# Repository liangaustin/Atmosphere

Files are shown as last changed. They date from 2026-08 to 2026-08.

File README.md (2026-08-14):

# Atmosphere：野外溪流 / 漂流点山洪与泥石流智能监测预警








`Atmosphere` 是一套面向**民间自发漂流活动与野外游泳区域（野泳池）**的低成本、高实效智能监测预警系统。它通过部署在溪流/漂流点的传感器单元，实时采集**土壤湿度、水流速、风速、温湿度**等环境数据，用多因子数学模型判定山洪与泥石流风险等级（0~3 级），并通过**网页监控 + 现场 LCD** 双端呈现，在危险来临前为现场人员争取撤离时间。

> ⚠️ 本系统是**辅助决策工具**，不替代救生员与现场安全管理。山洪预警的黄金法则是**上游预警**——请结合上游雨量/水位遥测站构成完整预警链。
> ⚠️ This is a **decision-support tool**, not a substitute for lifeguards or on-site safety management. The golden rule of flash-flood warning is **upstream early warning** — integrate with upstream rainfall/water-level stations for a complete chain.

## 目录 / Contents

- [主要功能 / Features](#主要功能--features)
- [项目背景 / Background](#项目背景--background)
- [团队分工 / Team](#团队分工--team)
- [硬件方案 / Hardware](#硬件方案--hardware)
- [预警模型 / Warning Model](#预警模型--warning-model)
- [快速开始 / Quick Start](#快速开始--quick-start)
- [项目结构 / Structure](#项目结构--structure)
- [版本历史 / Version History](#版本历史--version-history)
- [文档索引 / Docs](#文档索引--docs)
- [已知限制 / Known Limitations](#已知限制--known-limitations)
- [常见问题 / FAQ](#常见问题--faq)
- [二次开发 / Development](#二次开发--development)
- [贡献 / Contributing](#贡献--contributing)

---

## 主要功能 / Features

- **多传感器融合监测**：土壤湿度、水流速、风速、温湿度四路数据，同一块 Arduino Nano 采集。
- **山洪预警**：山洪路径 F（流量水平 + 流量突变），不受土壤门槛限制，流量暴涨即触发。
- **泥石流预警**：多因子危险指数 D（土湿 + 流量 + 突变 + 涨幅），含土壤饱和度门槛与滑动基准自适应。
- **分级预警**：0=正常 / 1=一级 / 2=二级 / 3=三级（**数字越大越严重**），网页 + LCD 双端显示。
- **现场 LCD**：1602 I2C 屏实时显示风速 / 土湿 / 流速 / 预警等级，不依赖电脑即可观测。
- **综合监控网页**：单页显示四卡 + 实时曲线 + 预警详情（端口 8080），支持水泵 PWM 滑块远程调速。
- **滑动基准自适应**：24 小时窗口 [P10,P95] 分位数归一化，自动适应当地气候，冷启动 15 分钟。
- **滞回防抖**：预警触发后保持（一级 10s / 二级 15s / 三级 20s），避免等级闪烁。
- **断线自愈**：传感器断线检测 + 串口自动重连 + 水泵独立供电防复位。

---

## 项目背景 / Background

民间自发漂流、野泳等亲水活动在山区溪流（天然河道）十分常见，但普遍缺乏有效监管，险情响应滞后。夏季短历时强降雨引发的山洪，可在数分钟内将涓涓细流变成汹涌洪流——据水利部副部长叶建春在国新办发布会介绍（2020年6月），**多年统计下山洪灾害伤亡人数约占洪涝灾害伤亡人数的 70%**，其中涉水游泳、溯溪属于高风险行为。

**核心目标**：以单点 300-400 元的低成本硬件，为漂流点 / 野泳区提供「采集 → 判断 → 预警 → 撤离」的完整闭环，同时保护周边平民安全。

---

## 团队分工 / Team

| 模块 / Module | 职责 / Responsibility | 负责人 / Lead |
|---|---|---|
| 硬件 / Hardware | 检测（收集数据） | 王立辉（Wang Li Hui） |
| 软件 / Software | Web APP（监控、警报、水泵控制） | 梁振宇（Austin Liang） |
| 预测 / Prediction | AI（分析数据、判断风险） | 待定 / TBD |

---

## 硬件方案 / Hardware

### 传感器单元（单点成本 300-400 元）

| 部件 / Part | 型号 / Spec | 接线 / Wiring |
|---|---|---|
| 主控 / MCU | Arduino Nano（ATmega328P，Optiboot，115200） | FQBN `arduino:avr:nano:cpu=atmega328` |
| 土壤湿度 / Soil | 电容式，AO→A2，DO→D2 | VCC→5V，GND→GND，断线检测（raw=1023 或抖动>200） |
| 水流速 / Flow | YF-S401 霍尔流量计 | 红→5V，黄→D8（信号），黑→GND；系数 3433.8 |
| 风速 / Wind | 三杯式风速计（0~5V 模拟输出） | 红→A0，黑→GND；V=ADC×5/1024，km/h=100×V |
| 温湿度 / DHT11 | 数字单总线 | s→D4，v→5V，g→GND |
| 水泵 / Pump | 直流抽水泵，D9 PWM 调速 | 软启动步长 10/20ms；**独立供电 + 共地** |
| 现场显示 / LCD | 1602 I2C（地址 0x27） | SCL→A5，SDA→A4 |
| 联网 / Network | NB-IoT 主 + LoRa 备（规划） | 低功耗、小数据量 |

> ⚠️ **供电铁律**：水泵必须**独立供电**（单独 5V 电源，只共地）。从 Arduino 5V 取电会拉垮 5V → CH340 掉电 → 板子复位断联。

### 软件环境

- Python 3（pyserial）+ Arduino IDE / arduino-cli
- 浏览器访问综合监控网页（http://localhost:8080）

---

## 预警模型 / Warning Model

**等级体系（数字越大越严重）**：`0 = 正常 / 1 = 一级 / 2 = 二级 / 3 = 三级（最高）`

```
最终等级 = max(泥石流 D, 山洪 F, 风速, 流量尖峰, 突变, 土壤饱和)   ← 0~3
```

| 路径 / Path | 公式 / Formula | 说明 / Note |
|---|---|---|
| 泥石流 D | `D = 0.30·S̄ + 0.35·Q̄ + 0.20·dQ̄ + 0.15·ΔS̄` | 土壤 <60% 时跳过本路径 |
| 山洪 F | `F = 0.60·Q̄ + 0.40·dQ̄` | 独立于土壤门槛，流量暴涨即触发 |
| 风速 | ≥25 / ≥40 / ≥60 km/h | 分别触发一级 / 二级 / 三级 |
| 流量尖峰 | 秒级变化率超当地 P95 | 二级；归一化 ≥0.8 → 一级 |
| 突变 | 土壤 5s 涨 ≥20% / 风速 60s 涨 ≥12 km/h | 立即一级 |
| 土壤饱和 | ≥85% 或超当地 P90 | 至少一级（不依赖流量） |

- **阈值**：D/F ≥ 0.45 → 一级；≥ 0.55 → 二级；≥ 0.75 → 三级。
- **滑动基准**：24h 窗口 [P10,P95] 归一化，冷启动 15 分钟；数据不足回退绝对值（Q_MAX=3 L/min、DQ_MAX=0.5，对齐 YF-S401 实测）。
- **滞回保持**：升级立即生效并保持；降级需超过保持时间（一级 10s / 二级 15s / 三级 20s）。
- 完整推导见 [`demo1/algorithm-iterations/`](demo1/algorithm-iterations/README.md)（v1/v2 技术文档，中英双语）。

---

## 快速开始 / Quick Start

```bash
# 1. 烧录固件（Arduino IDE，板卡 Nano + 新 Bootloader，115200）
#    demo1/zh-CN/第二版算法部分/beta5/FlowSensor.ino
#    或 arduino-cli：
#    arduino-cli compile --fqbn arduino:avr:nano:cpu=atmega328 <ino路径>
#    arduino-cli upload -p /dev/cu.usbserial-xxxx --fqbn arduino:avr:nano:cpu=atmega328 <ino路径>

# 2. 启动服务端（串口 /dev/cu.usbserial-14120）
cd demo1/zh-CN/第二版算法部分/beta5/
python3 -u server.py

# 3. 打开网页
http://localhost:8080
```

---

## 项目结构 / Structure

```
Atmosphere/
├── README.md                  # 本文件（新版导航）/ this file
├── README_CLASSIC.md          # 旧版 README 存档 / classic README archive
├── demo1/                     # Demo 1：算法归档 + 文档（zh-CN / en-US / weather / media）
│   ├── README.md              # demo1 详细导航（徽章 + 结构 + 快速开始）
│   ├── zh-CN/                 # 中文版：第一版算法部分(beta1-4) + 第二版算法部分(beta5)
│   ├── en-US/                 # 英文版（同结构）
│   ├── algorithm-iterations/  # 数学预警模型技术文档（v1/v2，中英）
│   ├── weather/               # 风速 + 温湿度模块（王立辉）
│   └── media/                 # 演示图片与视频
├── AustinLiang/               # 梁振宇工作区（土壤湿度）
├── wanglihui/                 # 王立辉工作区（风速）
└── GJJ/                       # 团队成员工作区
```

> 📂 **结构约定**：demo1 内中间层 = **算法版本**（第一版算法部分 = beta1-4，第二版算法部分 = beta5 起），最内层 = **实现迭代**（beta）。

---

## 版本历史 / Version History

| 版本 / Version | 算法 / Algorithm | 核心改动 / Key changes |
| --- | --- | --- |
| beta1 | v1 | 原始算法 D<0.30 无门槛；水泵 D7 数字开关 |
| beta2 | v1 | 加门槛（土壤<60%）+ 三级阈值 0.30→0.45 |
| beta3 | v1 | 水泵 D9 PWM 调速 + 网页滑块 + 功率显示 |
| beta4 | v1 | 尖峰滑动基准（自适应 P95）+ 整机功率（**Demo 1 最终版**） |
| **beta5** | **v2** | **LCD 显示（风速/土湿/流速/预警 0-3）+ 算法 v2（标定对齐、山洪 F、滞回、土壤饱和）+ 温湿度本地** |

> 🏁 **规划 / Plan**：Demo 1 完结于 beta4；beta5 起进入算法迭代阶段（数学预警模型 v2）。超声波水位方案已砍（与流速重叠，不做曼宁 70%）。

---

## 文档索引 / Docs

| 位置 / Path | 说明 / Description |
| --- | --- |
| [`demo1/README.md`](demo1/README.md) | Demo 1 详细导航（目录结构、快速开始、版本历史） |
| [`demo1/algorithm-iterations/`](demo1/algorithm-iterations/README.md) | 数学预警模型技术文档（v1/v2，中英双语，含优势/缺陷/迭代记录） |
| [`demo1/weather/`](demo1/weather/README.md) | 风速 + 温湿度模块（王立辉，网络服务 + Arduino 代码） |
| `demo1/media/` | 演示图片与视频 |

---

## 已知限制 / Known Limitations

1. **流量计量程窄 / Flow sensor range**：YF-S401 实测 0.05~3 L/min，真实洪水流量超量程——v2 标定参数面向当前测试环境，换环境需重新标定。
2. **突变阈值为经验值 / Empirical surge thresholds**：土壤 5s+20%、风速 60s+12km/h 未做统计标定。
3. **LCD 仅 ASCII / ASCII-only LCD**：1602 无中文字库，现场人员需熟悉 0~3 数字含义。
4. **硬阈值分级 / Hard thresholds**：0.45/0.55/0.75 阶梯跳变，无置信度/持续性判定（滞回已缓解闪断）。

---

## 常见问题 / FAQ

**Q1：水泵一开 Arduino 就重启/断连？**
水泵不能从 Arduino 5V 取电（会拉垮 5V → CH340 掉电 → 板子复位）。必须**独立 5V 电源**，GND 与 Arduino 共地，D9 只发 PWM 信号。

**Q2：LCD 不亮 / 花屏？**
① 检查 I2C 地址（默认 0x27，部分模块是 0x3F，改固件 `lcd(0x27, 16, 2)`）；② 确认 SCL→A5、SDA→A4 没接反；③ 旋转背光电位器调对比度。

**Q3：流速一直为 0？**
YF-S401 最小启动流量 0.3 L/min，低于此值转子不转（吹气测不了，必须通水）。接线：红→5V，黄→D8（信号），黑→GND。

**Q4：风速数值异常 / 静止也有读数？**
三杯式风速计部分型号存在零点偏移（静止时输出 ~0.1-0.2V ≈ 10-20 km/h）。可在固件里读静止 ADC 值做零点校准（读数减去零点再换算）。

**Q5：网页风速显示 0 / 离线？**
风速默认来自外部电脑 HTTP 服务（`192.168.1.200:8001/wind`），该服务离线时风速路径失效。风速传感器接入本机 A0 后自动切换本地模式（`wind_source: local`）。

**Q6：串口连不上 / 找不到端口？**
拔插 USB 后端口号会变，用 `ls /dev/cu.* | grep usbserial` 确认，改 `server.py` 里的 `SERIAL_PORT`。烧录时波特率选 115200（Optiboot 新 Bootloader）。

**Q7：预警一直不触发？**
① 土壤 <60% 时泥石流路径跳过（正常）；② 滑动基准冷启动需 15 分钟；③ 检查网页预警卡里的 D/F 数值是否在阈值附近（0.45/0.55/0.75）。

---

## 二次开发 / Development

- **算法迭代**：新算法版本在 `demo1/algorithm-iterations/` 归档，每代一份技术文档（优势 / 缺陷 / 特点），随迭代更新。
- **固件**：`FlowSensor.ino` 模块化，新增传感器 = 加引脚定义 + 每秒块加采集 + JSON 加字段。
- **服务端**：`server.py` 内嵌网页 + 预警模型，五路径独立计算，可单独迭代。
- **协作开发**：双 OpenClaw 协作（桥 8090 + 对端 8131），任务经桥下发，代码经桥/仓库同步。

---

## 贡献 / Contributing

欢迎提交 Issue 与 PR。涉及硬件接线、标定参数、算法阈值的改动，请在提交前更新对应文档（`demo1/algorithm-iterations/`）。本项目为教学 / 竞赛 / 公益性质，文档一律不署名。

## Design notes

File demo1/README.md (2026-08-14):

# 🌊 Atmosphere — Demo 1

> **山洪 + 泥石流智能监测预警 · 野外溪流 / 漂流点**
> **Flash-flood & debris-flow early warning for outdoor streams & drifting sites**







---

## 📑 目录 / Contents

- [📖 项目简介 / Overview](#-项目简介--overview)
- [🎯 应用场景 / Scenarios](#-应用场景--scenarios)
- [🏗️ 系统架构 / Architecture](#%EF%B8%8F-系统架构--architecture)
- [🔌 硬件连接 / Hardware Wiring](#-硬件连接--hardware-wiring)
- [📁 目录结构 / Folder Structure](#-目录结构--folder-structure)
- [🚀 快速开始 / Quick Start](#-快速开始--quick-start)
- [🧠 预警模型 / Warning Model](#-预警模型--warning-model)
- [📜 版本历史 / Version History](#-版本历史--version-history)
- [📄 文档索引 / Docs](#-文档索引--docs)
- [⚠️ 已知问题 / Known Issues](#️-已知问题--known-issues)

---

## 📖 项目简介 / Overview

**中文**：Atmosphere 面向野外溪流、漂流点等场景，实时采集**土壤湿度、水流速、风速、温湿度**四类环境数据，通过网页与 LCD 双端监控，用数学模型（泥石流危险指数 + 山洪流量近似 + 滑动基准 + 滞回保持）输出 **0~3 分级预警**，辅助判断山洪、泥石流风险。Demo 1 打通「采集 → 控制 → 监控 → 预警」全链路。

**English**: Atmosphere monitors soil moisture, water flow, wind speed, and temperature/humidity at outdoor streams and drifting sites. It provides live monitoring via web dashboard **and on-site LCD**, and outputs **0–3 graded warnings** via mathematical models (debris-flow danger index + flash-flood flow approximation + sliding baseline + hysteresis hold). Demo 1 completes the full "sense → control → monitor → warn" pipeline.

---

## 🎯 应用场景 / Scenarios

| 场景 / Scenario | 系统做什么 / What the system does |
| --- | --- |
| 🏞️ 漂流点 / Drifting sites | 上游暴雨时水流暴涨 → 山洪路径 F 秒级响应，现场 LCD 显示预警等级 |
| 🏔️ 泥石流沟谷 / Debris-flow valleys | 土壤饱和（≥85% 或超当地 P90）→ 持续一级预警，不依赖流量 |
| 🌪️ 强对流天气 / Severe convection | 风速 ≥25/40/60 km/h 分级预警 + 60 秒突涨 12 km/h 秒级升级 |
| 📡 偏远无网现场 / Remote sites | LCD 本地显示四路核心数据，网页仅作中控台 |

---

## 🏗️ 系统架构 / Architecture

```
┌─────────────┐   ┌──────────────┐   ┌───────────────┐
│ Arduino Nano│──▶│  server.py    │──▶│  Web :8080    │
│ 土壤/流速/DHT│   │  模型 v2 计算 │   │  曲线+预警卡  │
│ 水泵 PWM/LCD │◀──│  LCD 下发     │   └───────────────┘
└─────────────┘   │  (D行协议)    │
     ▲ 115200     └──────▲───────┘
     │                    │ HTTP
┌────┴─────────┐  ┌───────┴──────┐
│ 风速电脑 :8001│──│ 另一台 OpenClaw│（协作开发）
│ wind JSON    │  │  :8131        │
└──────────────┘  └──────────────┘
```

- **采集端**：Arduino Nano（土壤 A2/D2、流速 D8、DHT11 D4、水泵 D9、LCD I2C）
- **服务端**：`server.py`（串口 115200 + 模型推理 + 网页 8080 + LCD 数据下发）
- **风速**：外部电脑 HTTP `192.168.1.200:8001/wind` 接入（LCD 显示 + 预警模型）

---

## 🔌 硬件连接 / Hardware Wiring

**主控 / Controller**：Arduino Nano（ATmega328P，新 Bootloader，串口 115200）

| 设备 / Device | 接线 / Wiring |
| --- | --- |
| 土壤湿度 / Soil moisture | AO→A2，DO→D2，VCC→5V，GND→GND |
| 流速 YF-S401 / Flow | 红 Red→5V，黄 Yellow→D8（信号），黑 Black→GND |
| 温湿度 DHT11 | s→D4，v→5V，g→GND |
| 水泵 / Pump | D9（PWM 调速，软启动，**独立供电 + 共地**） |
| LCD 1602 (I2C) | SCL→A5，SDA→A4（地址 0x27） |
| 风速 / Wind | 外部电脑 Arduino UNO A0（0~5V 三杯式），HTTP 转发 |

> ⚠️ YF-S401 实测量程 **0.05~3 L/min**，系数 3433.8（脉冲数 / 3433.8 = 升）；低于启动流量转子不转。

---

## 📁 目录结构 / Folder Structure

```
demo 1/
├── README.md                    # 本文件（中英双语导航）
├── zh-CN/                       # 中文版（语言 → 算法版本 → 实现迭代）
│   ├── 第一版算法部分/           # 第一版算法：风速基准线 + 滑动基准（beta1-4）
│   │   ├── beta1/ … beta4/      # 每版：FlowSensor.ino + server.py + 说明文档.md
│   └── 第二版算法部分/           # 第二版算法：标定对齐 + 快速滑动基准（beta5 起）
│       └── beta5/               # LCD 显示 + 算法 v2 + 风速接入
├── en-US/                       # 英文版（同结构 / same structure）
│   ├── algorithm-v1/beta1-4/
│   └── algorithm-v2/beta5/
├── algorithm-iterations/        # 数学预警模型技术文档（v1/v2，中英）
├── weather/                     # 风速 + 温湿度模块（网络服务 + Arduino）
└── media/                       # 图片与视频
```

> 📂 **结构约定**：中间层 = **算法版本**（v1/v2），最内层 = **实现迭代**（beta）。beta1-4 属第一版算法；beta5 起属第二版算法（数学预警模型 v2，详见 `algorithm-iterations/`）。

---

## 🚀 快速开始 / Quick Start

```bash
# 1. 烧录固件（Arduino IDE，板卡 Nano + 新 Bootloader，115200）
#    zh-CN/第二版算法部分/beta5/FlowSensor.ino

# 2. 启动服务端（串口 /dev/cu.usbserial-14120）
python3 -u server.py

# 3. 打开网页
http://localhost:8080
```

> 风速来自 `http://192.168.1.200:8001/wind`，需保持该服务在线（10 秒窗口判在线）。

---

## 🧠 预警模型 / Warning Model

详细技术文档（中英双语、含优势/缺陷/迭代记录）见 **`algorithm-iterations/`**：

| 文档 / Doc | 内容 / Content |
| --- | --- |
| [v1 第一版技术文档](./algorithm-iterations/zh-CN/数学预警模型第一版技术文档.md) | 风速基准线 + 滑动基准（beta1-4） |
| [v2 第二版技术文档](./algorithm-iterations/zh-CN/数学预警模型第二版技术文档.md) | 标定对齐 + 快速滑动基准（beta5 起） |

**一句话版 / TL;DR**：

```
最终等级 = max(泥石流 D, 山洪 F, 风速, 流量尖峰, 突变, 土壤饱和)   ← 0~3
D = 0.30·S̄ + 0.35·Q̄ + 0.20·dQ̄ + 0.15·ΔS̄     （泥石流，土壤<60% 跳过）
F = 0.60·Q̄ + 0.40·dQ̄                          （山洪，不受土壤门槛限制）
```

- **等级 / Levels**：0=正常 · 1=一级 · 2=二级 · **3=三级（最高）**
- **滑动基准**：24h 窗口 [P10,P95] 归一化，冷启动 **15 分钟**
- **滞回保持**：触发后保持（一级 10s / 二级 15s / 三级 20s），防抖
- **标定**：Q_MAX=3 L/min、DQ_MAX=0.5、尖峰回退 /0.5（对齐 YF-S401 实测）

---

## 📜 版本历史 / Version History

| 版本 / Version | 算法 / Algorithm | 核心改动 / Key changes |
| --- | --- | --- |
| beta1 | v1 | 原始算法 D<0.30 无门槛；水泵 D7 数字开关 |
| beta2 | v1 | 加门槛（土壤<60%）+ 三级阈值 0.30→0.45 |
| beta3 | v1 | 水泵 D9 PWM 调速 + 网页滑块 + 功率显示 |
| beta4 | v1 | 尖峰滑动基准（自适应 P95）+ 整机功率（**Demo 1 最终版**） |
| **beta5** | **v2** | **LCD 显示（风速/土湿/流速/预警 0-3）+ 算法 v2（标定对齐、山洪 F、滞回、土壤饱和）+ 温湿度本地** |

> 🏁 **规划 / Plan**：Demo 1 完结于 beta4，beta5 起进入**算法迭代阶段**（数学预警模型 v2，归档 `algorithm-iterations/`）。超声波水位方案已砍（与流速重叠，不做曼宁 70%）。

---

## 📄 文档索引 / Docs

| 位置 / Path | 说明 / Description |
| --- | --- |
| `algorithm-iterations/` | 数学预警模型技术文档（v1/v2，中英） |
| `weather/` | 风速 + 温湿度模块（王立辉，网络服务 + Arduino 代码） |
| `media/` | 演示图片与视频 |
| `README.md` | 本文件（导航 + 版本历史） |

---

## ⚠️ 已知问题 / Known Issues

1. **流量计量程窄 / Flow sensor range**：YF-S401 仅 0.05~3 L/min，真实洪水流量超量程——v2 标定参数面向当前测试环境，换环境需重新标定。
2. **风速依赖外部电脑 / Wind dependency**：8001 服务离线时风速路径失效（LCD 风速显示 0）；物理迁移到综合板为后续项。
3. **硬阈值分级 / Hard thresholds**：0.45/0.55/0.75 阶梯跳变，无置信度/持续性判定（滞回已缓解闪断）。

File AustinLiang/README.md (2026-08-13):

# Austin（梁振宇）— 软件部分

## soil-monitor — 土壤湿度传感器

- `SoilMonitor.ino` — Arduino Nano 程序（AO→A0, DO→D2, VCC→5V, GND→GND）
  - 输出 JSON：raw / percent / dry / jitter / connected
  - 带断线检测（抖动 >200 或 raw >1010 判为脱落）
  - 500ms 采样间隔
- `server.py` — Web 实时监控（端口 8080，环形仪表盘）
- `log_humidity.py` — 串口数据日志记录

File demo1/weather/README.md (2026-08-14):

# 风速 + 温湿度模块（王立辉负责）

野外溪流/漂流点山洪智能监测预警系统 —— 风速 + 温湿度监测单元。

## 模块组成

| 文件 | 说明 |
| ---- | ---- |
| `01_WindSensor.ino` | 风速传感器基础版：三杯式风速计 → 风速 km/h / m/s，超 10 km/h 板载 LED 报警 |
| `wind_server.py` | 基础版配套转发服务：读串口 → HTTP :8001/wind 返回 JSON |
| `风速+温湿度/` | 完整版：风速 + DHT11 温湿度 + 网页仪表盘 + 智能预警 |

## 硬件接线

- 风速传感器：红线 → A0，黑线 → GND（三杯式风速计，0~5V 模拟输出）
- DHT11：v → 5V，s → D4，g → GND
- 报警 LED：板载 D13

## 运行方式

```bash
# 1. 烧录 Arduino（完整版）
#    Arduino IDE 打开 风速+温湿度/02_WindTempHumidity.ino，选 Arduino UNO + 对应端口
#    波特率 9600，串口输出 CSV：电压,风速,温度,湿度

# 2. 启动转发服务（8001 端口，供局域网其他电脑调用）
cd 风速+温湿度/server
python3 wind_server.py        # 改 SERIAL_PORT 为实际串口号

# 3. 启动网页仪表盘（3000 端口）
npm install                   # 首次运行装依赖
node server.js
# 浏览器打开 http://localhost:3000
```

Windows 下可双击 `风速+温湿度/server/启动仪表盘.bat` 一键启动（自动先起 8001 转发，再起仪表盘）。

## 架构

```
Arduino UNO（串口 9600，CSV 输出）
   │
   ▼
wind_server.py ── 独占串口，解析数据，缓存最新值
   │              HTTP :8001/wind → {"wind_kmh","wind_ms","temp","hum","time"}
   ▼
server.js ── 每 1 秒轮询 8001，加分预警引擎 + SSE 推送
   │
   ▼
浏览器 http://localhost:3000（仪表盘：风速曲线 / 温湿度 / 阵风 / 30 分钟基准线 / 分级预警）
```

## 与综合监控联动

本模块的 `http://<风速电脑IP>:8001/wind` JSON 接口被综合监控网页（土壤湿度 + 流速 + 水泵）调用，显示风速、温度、湿度；10 秒无响应自动判为离线。

## 备注

- `wind_server.py`（模块根目录）为基础版配套服务，只解析 `01_WindSensor.ino` 的文本格式；`风速+温湿度/server/wind_server.py` 为完整版，同时兼容文本格式和 CSV 格式
- 接线图见 `风速+温湿度/图片1~3.jpg`

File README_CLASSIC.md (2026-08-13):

# Atmosphere项目

## 中文版本

### 项目概述

针对民间自发漂流活动及野外游泳区域（野泳池）缺乏有效监管、险情响应滞后等安全问题，我们计划推出一套低成本、高实效的智能监测预警解决方案。

**核心目标**：解决野外溪流等场景的气象/洪水/内涝安全问题, 同时保护周围平民百姓安全。

---

### 团队分工

| 模块 | 职责 | 负责人 |
|---|---|---|
| 硬件 | 检测（收集数据） | 王立辉Wang Li Hui |
| 软件 | Web APP（通知、警报） | 梁振宇AustinLiang |
| 预测 | AI（分析数据、判断风险） | - |

---

### 方案详情

#### 1. 硬件：精准监测，成本可控

- **成本控制**：单点硬件设备综合成本严格控制在 **300-400 元** 区间，确保项目具备高性价比与可复制性。
- **核心功能**：设备集成高灵敏度水流速度传感器，实现实时动态监测，并内置历史流速趋势分析模块。通过对比实时数据与过去时间段的水流变化规律，系统可智能过滤自然波动带来的误报，精准判定危险临界值，为后续警报提供确切的数据支撑。

#### 2. 软件：联动响应，信息可视

- **系统定位**：软件作为硬件的配套辅助管理端，负责数据处理与指令下发。
- **警报机制**：当监测数据触发危险阈值，系统将立即推送紧急预警信号至工作人员终端，确保险情在第一时间得到人工确认与干预。

#### 3. 现场部署方案

软件显示界面将落地安装在野泳池及漂流起终点旁的电子显示屏（电视）周边。这种"现场投屏"设计，确保岸边巡视人员及救生员能够直观、实时获取警报状态，极大缩短从"发现险情"到"实施救援"的反应链路，可以让人们危险来临前尽快撤离，保卫安全。

---

## English Version

### Team Division

| Module | Responsibility | Person in Charge |
|---|---|---|
| Hardware | Detection (data collection) | Wang Li Hui |
| Software | Web APP (notifications, alerts) | Liang Austin |
| Prediction | AI (data analysis, risk assessment) | - |

---

### Solution Details

#### 1. Hardware: Precision Monitoring, Controllable Cost

- **Cost Control**: The comprehensive cost of a single hardware device is strictly controlled within the range of **300-400 yuan**, ensuring the project has high cost-effectiveness and replicability.
- **Core Functions**: The device integrates a high-sensitivity water flow velocity sensor to achieve real-time dynamic monitoring, and includes a built-in historical flow rate trend analysis module. By comparing real-time data with water flow change patterns from past time periods, the system can intelligently filter false alarms caused by natural fluctuations, accurately determine dangerous threshold values, and provide definite data support for subsequent alerts.

#### 2. Software: Linked Response, Information Visualization

- **System Positioning**: Software serves as the supporting management terminal for hardware, responsible for data processing and command distribution.
- **Alert Mechanism**: When monitoring data triggers dangerous thresholds, the system will immediately push emergency warning signals to staff terminals, ensuring that dangerous situations are confirmed and intervened at the first moment.

#### 3. On-Site Deployment Plan

The software display interface will be installed on electronic display screens (TVs) near wild swimming pools and drift starting/ending points. This "on-site casting" design ensures that shore patrol personnel and lifeguards can intuitively and real-time obtain alert status, greatly shortening the response chain from "discovering danger" to "implementing rescue", allowing people to evacuate as soon as possible before danger arrives and ensuring safety.

---

-Last but not least, wishing this project a successful completion!

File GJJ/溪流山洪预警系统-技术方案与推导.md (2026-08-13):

# 溪流山洪预警系统 —— 基于 Arduino + 曼宁公式的技术推导

> 技术方案与推导文档 · Arduino + 曼宁公式
> 版本：v1.0 | 编制日期：2026-08-11 | 适用范围：山区/丘陵天然溪流，梯形断面概化

---

## 1. 项目背景与目标

夏季溪流（天然河道，山区/丘陵地形）是游泳消暑的热门场所。然而，上游短历时强降雨（山洪暴发）可在数分钟内将涓涓细流变成汹涌洪流，令游泳者猝不及防。据中国气象局统计，山洪灾害年均致死人数占洪涝总死亡的 60% 以上，其中涉水游泳、溯溪是高风险行为。

本项目的目标是设计一套低成本、可现场部署的实时监测预警系统：

- **实时监测**：采集溪流水位/流速，计算流量；
- **提前预警**：当水流条件达到危险阈值时，触发声光报警与远程通知；
- **保护游泳者**：为下游游泳区域提供足够的撤离时间窗口。

系统定位为辅助安全工具，不替代救生员与现场安全管理。

## 2. 技术方案总览

系统采用分层架构，数据自底向上流动：

```
感知层（传感器）        → 水位、流速、雨量等物理量采集
    ↓
数据层（Arduino 采集）  → 脉冲计数、模数转换、中值滤波
    ↓
计算层（曼宁公式）      → 由水位推算过水断面与流速、流量
    ↓
判定层（阈值判定）      → 临界流速、d·v 乘积、水位涨率
    ↓
预警层（声光/远程）     → LED 分级显示、蜂鸣器、无线发送
```

**数据流说明：**

1. 超声波传感器（HC-SR04）周期性地测量水面到传感器的距离，换算为当前水深 h(t)；
2. Arduino 对连续 N 次测量做中值滤波，获得平滑水深值；
3. 将水深代入预置的断面几何参数与曼宁公式，算出瞬时流速 v 和流量 Q；
4. 比较 v、d·v（水深×流速）、dh/dt 与预设阈值，判定危险等级；
5. 驱动对应颜色的 LED 与蜂鸣器模式，同时通过串口/无线模块发送数据报文。

系统亦可选配雨量计（板式或翻斗式）作为上游预警的提前量输入。

## 3. 曼宁公式推导

### 3.1 明渠均匀流基本假设

天然溪流可近似为明渠恒定均匀流，其成立需满足以下假设：

- **恒定流**：流量 Q 不随时间变化（在短时间窗口内近似成立）；
- **均匀流**：沿流向水深 h、断面形状、流速 v 不变；
- **重力-阻力平衡**：水体重力沿流向的分力与河床边界阻力相等，水面线平行于河床。

此时不必求解 Saint-Venant 方程组，可直接用阻力公式计算平均流速。

### 3.2 从 Chézy 到 Manning

法国工程师 Chézy（1769）最先给出均匀流流速公式：

```
v = C · √(R · S)
```

其中 C 为 Chézy 系数（量纲 L^(1/2)/T）、R 为水力半径、S 为底坡（无量纲）。

爱尔兰工程师 Manning（1891）根据大量河流与渠道实测数据，发现 C 并不恒定，而与 R^(1/6) 近似成正比。他提出经验公式：

```
v = (1/n) · R^(2/3) · S^(1/2)
```

这就是曼宁公式，其中：

| 符号 | 名称 | 单位 | 说明 |
|---|---|---|---|
| v | 断面平均流速 | m/s | — |
| n | 糙率（Manning's n） | s/m^(1/3) | 经验值，表征河床粗糙度 |
| R | 水力半径 | m | R = A / P |
| A | 过水断面面积 | m² | 横截面中水流占据的面积 |
| P | 湿周 | m | 断面中水体与河床接触的周长 |
| S | 底坡（能坡） | m/m（无量纲） | 对于均匀流 S = 河床比降 |

n 是纯经验参数，无严格物理推导。Chow（1959）编纂了大量天然河道的 n 值查表（见第 7 节）。

### 3.3 梯形断面几何推导

天然溪流断面通常不规则，工程上常概化为梯形（对称边坡 m:1，即水平:垂直）：

```
        水面 ~~~~~~~~~~~~~
          ______________
         /              \
        /                \    ← 边坡 m:1
       /                  \
  ____/____________________\____ 河床
  |←—— b（底宽）——→|
```

设底宽为 b（m），水深为 h（m），边坡系数为 m（水平 / 垂直），则：

**过水断面面积 A：**

```
A = (b + m · h) · h
```

**湿周 P（梯形两腰加底边）：**

```
P = b + 2h · √(1 + m²)
```

**水力半径 R：**

```
R = A / P = (b + m·h)·h / [b + 2h·√(1 + m²)]
```

### 3.4 流量公式

将 R 代入曼宁公式，乘以面积得流量：

```
Q = v · A = (1/n) · A · R^(2/3) · S^(1/2)
```

### 3.5 完整数值算例

给定参数：

- 底宽 b = 3.0 m
- 边坡系数 m = 1.5（较缓的梯形）
- 底坡 S = 0.01（1%，即每 100 m 下降 1 m）
- 糙率 n = 0.035（天然溪流，碎石河床，清洁直段）

计算三种水深下的水力要素：

| h (m) | A (m²) | P (m) | R (m) | R^(2/3) | v (m/s) | Q (m³/s) |
|---|---|---|---|---|---|---|
| 0.50 | 1.875 | 4.80 | 0.390 | 0.534 | 1.53 | 2.86 |
| 1.00 | 4.500 | 6.61 | 0.681 | 0.774 | 2.21 | 9.95 |
| 1.50 | 7.875 | 8.41 | 0.937 | 0.957 | 2.74 | 21.5 |

**数值验算示例（h = 0.50 m）：**

- 面积：A = (3.0 + 1.5 × 0.5) × 0.5 = 3.75 × 0.5 = 1.875 m²
- 湿周：P = 3.0 + 2 × 0.5 × √(1 + 1.5²) = 3.0 + 1.0 × √3.25 = 3.0 + 1.803 = 4.803 m
- 水力半径：R = 1.875 / 4.803 = 0.3904 m
- R^(2/3) = 0.3904^(2/3) = e^[(2/3)×ln(0.3904)] = e^(-0.627) = 0.534
- 流速：v = (1/0.035) × 0.534 × √0.01 = 28.57 × 0.534 × 0.10 = 1.53 m/s
- 流量：Q = 1.53 × 1.875 = 2.86 m³/s

量纲校验：v 的量纲为 [1/n]·[L^(2/3)]·[1] = (1 / T·L^(-1/3)) · L^(2/3) = L/T = m/s ✓；Q = m/s × m² = m³/s ✓。

> ⚠️ 值得注意的是，在底坡 S = 1% 的陡溪中，即使水深仅 0.5 m，流速已达 1.53 m/s —— 远超成人站立临界流速（见第 5 节），危险程度不容小觑。

## 4. 传感器选型与原理

### 4.1 主控

选择 Arduino Uno R3 或 Arduino Nano（ATmega328P，5V/16MHz），理由：

- 宽供电范围（7-12V DC 或 5V USB）；
- 多路 GPIO、外部中断引脚（D2/D3）适合脉冲计数；
- 生态成熟，库丰富，适合快速原型；
- 功耗低，适合太阳能供电的野外部署。

### 4.2 YF-S201 霍尔水流量传感器

YF-S201 内部结构为磁性叶轮 + 霍尔效应传感器：水流推动叶轮旋转，每转一圈霍尔元件产生一个脉冲。常见标定关系：

```
流量 Q_L (L/min) = 脉冲频率 f (Hz) / 7.5
```

即每升水约产生 450 个脉冲（7.5 Hz 对应 1 L/min）。量程 1–30 L/min，耐压 ≤ 1.75 MPa，适用于 DN15（1/2 英寸）管径。

接线：红线 VCC（5–24V）、黑线 GND、黄线信号（集电极开路，需 10kΩ 上拉至 VCC）。

### 4.3 关键工程设计问题：管流传感器如何测溪流？

> 诚实说明：YF-S201 设计用于封闭管道满管流，不能直接放入天然溪流测量 —— 溪流断面远大于传感器管径，且非满管流会导致叶轮裸露或进气，测量完全失效。

对此，本文给出两种工程解法，推荐方案 A：

#### 方案 A（推荐）：水位-流量关系法

在溪流断面正上方架设 HC-SR04 超声波测距模块，测量传感器到水面的距离，进而反算水深 h：

```
h = H_total − D_measured
```

其中 H_total 为传感器安装高度至河床底的已知距离（安装时标定），D_measured 为超声波实测距离。获得 h 后，代入曼宁公式 Q(h) 直接换算流量与流速。

HC-SR04 参数：测量范围 2–400 cm，精度 ±3 mm，Trig/Echo 触发模式，5V 供电。

优势：非接触测量，无需改造河道，不受漂浮物缠绕影响。

#### 方案 B：流速测点标定法

将流速传感器（可用螺旋桨流速仪或改良的管道流速探头）固定在断面主流区某深度，实测点流速 v_meas。由于曼宁公式给出的是断面平均流速，可用实测值反算/率定糙率 n：

```
n = R^(2/3) · S^(1/2) / v_meas
```

在糙率 n 标定完成后，即可用水位 h → R(h) → 曼宁公式 → v 推算全场流速。

缺点：单点流速不能代表全断面平均流速，需乘以经验修正系数（约 0.8–0.9），且传感器浸入水中易被杂物缠绕。

### 4.4 可选传感器

| 传感器 | 用途 | 说明 |
|---|---|---|
| 翻斗式雨量计 | 上游降雨预警 | 每个翻斗 ≈ 0.2–0.5 mm 降雨，提前量关键 |
| DS18B20 温度探头 | 水温监测 | 游泳舒适度参考（15℃ 以下有失温风险） |
| 大气压力传感器 (BMP280) | 辅助气象 | 气压骤降可辅助判断风暴来临 |

## 5. 危险判定阈值推导

### 5.1 人体流水稳定性力学分析

人站立于流水中，受到水流的拖曳力（drag force）：

```
F_D = 0.5 · ρ · C_D · A_p · v²
```

其中：

- ρ = 1000 kg/m³（清水密度）
- C_D ≈ 1.0–1.2（人体为钝体，取 1.0）
- A_p 为人体在来流方向的迎水投影面积（m²），随水深 h 变化

人体抵抗水流的摩擦力来自足底与河床：

```
F_f = μ · W'
```

其中 μ ≈ 0.5–0.7（橡胶/赤足与岩石间静摩擦系数，取 0.6），W' 为水中有效重量（扣除浮力）。成人平均体重约 700 N，水中约 90% 体积没入时浮力约 630 N，故 W' ≈ 70 N。

则 F_f ≈ 0.6 × 70 = 42 N。

临界条件 F_D = F_f：

```
0.5 × 1000 × 1.0 × A_p × v_c² = 42
```

- 水深及膝（h ≈ 0.4 m），A_p ≈ 0.25 m² → v_c ≈ √(84/250) = 0.58 m/s
- 水深及腰（h ≈ 0.8 m），A_p ≈ 0.50 m² → v_c ≈ √(84/500) = 0.41 m/s
- 水深及胸（h ≈ 1.2 m），A_p ≈ 0.70 m² → v_c ≈ √(84/700) = 0.35 m/s

**结论**：成人可稳定站立的流速上限随水深增大而降低，工程上常取 **0.5–0.6 m/s 为行走困难阈值，1.0–1.2 m/s 为无法站立/被冲倒阈值**。

### 5.2 水深-流速乘积标准

白水救援（Whitewater Rescue）与水安全工程中常用 d·v 乘积（depth × velocity product）作为综合危险指标：

| d·v (m²/s) | 危险等级 | 说明 |
|---|---|---|
| < 0.2 | 安全 | 成人可稳定涉水 |
| 0.2–0.4 | 注意 | 儿童危险，成人行走困难 |
| > 0.4 | 危险 | 成人无法站稳，禁止涉水 |

### 5.3 由 v = 0.5 m/s 反解临界水深与临界流量

沿用第 3.5 节的断面参数（b = 3.0 m, m = 1.5, S = 0.01, n = 0.035），求解 v(h) = 0.5 m/s 对应的 h_c：

用迭代法（试算）：

- 试 h = 0.10 m：A = 0.315 m², P = 3.36 m, R = 0.0937 m, R^(2/3) = 0.206, v = 0.590 m/s（偏高）
- 试 h = 0.08 m：A = 0.250 m², P = 3.29 m, R = 0.0759 m, R^(2/3) = 0.179, v = 0.512 m/s
- 试 h = 0.078 m：A = 0.243 m², P = 3.28 m, R = 0.0741 m, R^(2/3) = 0.176, v = 0.504 m/s ✓

**临界水深 h_c ≈ 0.078 m，临界流量 Q_c = v × A ≈ 0.504 × 0.243 ≈ 0.12 m³/s。**

物理意义：在该宽浅（b=3m）、大底坡（S=1%）的溪流中，只要水深超过约 8 cm，流速即超过成人安全站立阈值。这解释了为何"看着水不深"的山溪实际极为危险——流速早已在不经意间致命。

同理，d·v = 0.4 m²/s 对应的临界水深约 h ≈ 0.33 m（v ≈ 1.21 m/s），即水深超过小腿时已进入红区。

### 5.4 预警分级

| 等级 | 触发条件 | 响应 |
|---|---|---|
| 🔵 蓝色（关注） | v > 0.3 m/s 或降雨开始 | 蓝色 LED 常亮，提醒游泳者注意 |
| 🟡 黄色（警告） | v > 0.5 m/s 或 d·v > 0.4 m²/s | 黄色 LED 闪烁 + 蜂鸣器间歇鸣响（1 Hz） |
| 🔴 红色（立即撤离） | v > 1.0 m/s 或 dh/dt > 0.3 m/h 或雨强 > 30 mm/h | 红色 LED 高频闪烁 + 蜂鸣器长鸣；远程推送报警 |

其中 dh/dt（水位上涨速率）和雨强是比流速更灵敏的山洪前兆。单独依赖本站水位/流速会有滞后（见第 8 节）。

## 6. Arduino 实现

### 6.1 引脚接线表

| Arduino 引脚 | 连接设备 | 说明 |
|---|---|---|
| D2 (INT0) | YF-S201 信号线（黄） | 外部中断，脉冲计数 |
| D3 | HC-SR04 Trig | 超声波触发 |
| D4 | HC-SR04 Echo | 超声波回波 |
| D5 | 蓝色 LED（经 220Ω） | 关注指示 |
| D6 | 黄色 LED（经 220Ω） | 警告指示 |
| D7 | 红色 LED（经 220Ω） | 危险指示 |
| D8 | 有源蜂鸣器 | 报警 |
| D9 | 可选：雨量计输入 | 翻斗脉冲计数 |
| A0 | 可选：DS18B20（OneWire） | 水温 |
| TX/RX | 可选：ESP8266 / LoRa 模块 | 远程通信 |
| 5V / GND | 各传感器 VCC / GND | 公共供电 |

### 6.2 核心代码

```cpp
// ====== 溪流山洪预警系统 ======
// 基于 HC-SR04 超声波水位 + 曼宁公式 + 分级报警

#include <NewPing.h>   // 超声波库（需安装）

// ---------- 引脚定义 ----------
#define TRIG_PIN    3
#define ECHO_PIN    4
#define LED_BLUE    5
#define LED_YELLOW  6
#define LED_RED     7
#define BUZZER      8

// ---------- 断面参数（安装时实测标定）----------
const float B      = 3.0;    // 底宽 (m)
const float M      = 1.5;    // 边坡系数
const float N_MAN  = 0.035;  // 曼宁糙率
const float S_SLOPE = 0.01;  // 底坡
const float H_TOTAL = 2.50;  // 传感器距河床总高 (m)，安装时激光测距标定

// ---------- 预警阈值 ----------
const float V_BLUE   = 0.3;  // m/s
const float V_YELLOW = 0.5;  // m/s
const float V_RED    = 1.0;  // m/s
const float DV_CRIT  = 0.4;  // m²/s，成人危险 d·v 乘积
const float DH_RATE  = 0.3;  // m/h，水位上涨速率

// ---------- 采样参数 ----------
const int   SAMPLE_COUNT = 10;    // 中值滤波样本数
const float SAMPLE_NORMAL = 60000; // 正常采样间隔 60s (ms)
const float SAMPLE_FAST   = 5000;  // 加速采样间隔 5s (ms)

NewPing sonar(TRIG_PIN, ECHO_PIN, 400); // 最大距离 400 cm
float prevH = 0.0;
unsigned long prevTime = 0;

// ---------- 梯形断面水力计算 ----------
float calcArea(float h) {
  return (B + M * h) * h;
}

float calcWettedPerimeter(float h) {
  return B + 2.0 * h * sqrt(1.0 + M * M);
}

float calcHydraulicRadius(float h) {
  if (h <= 0.001) return 0.0;
  float a = calcArea(h);
  float p = calcWettedPerimeter(h);
  return a / p;
}

// 曼宁公式：v = (1/n) * R^(2/3) * S^(1/2)
float calcVelocity(float h) {
  if (h <= 0.001) return 0.0;
  float r = calcHydraulicRadius(h);
  return (1.0 / N_MAN) * pow(r, 2.0/3.0) * sqrt(S_SLOPE);
}

float calcDischarge(float h) {
  float v = calcVelocity(h);
  float a = calcArea(h);
  return v * a;
}

// ---------- 中值滤波（冒泡排序取中位）----------
float medianFilter(float *arr, int n) {
  float tmp[n];
  for (int i = 0; i < n; i++) tmp[i] = arr[i];
  for (int i = 0; i < n-1; i++)
    for (int j = i+1; j < n; j++)
      if (tmp[i] > tmp[j]) { float t = tmp[i]; tmp[i] = tmp[j]; tmp[j] = t; }
  return tmp[n/2];
}

// ---------- 读取超声波水深 ----------
float readDepth() {
  float samples[SAMPLE_COUNT];
  for (int i = 0; i < SAMPLE_COUNT; i++) {
    float d_cm = sonar.ping_cm();  // 距离水面 (cm)
    if (d_cm == 0) d_cm = H_TOTAL * 100; // 超量程当作河床
    samples[i] = (H_TOTAL * 100.0 - d_cm) / 100.0; // 水深 (m)，限制 ≥0
    if (samples[i] < 0) samples[i] = 0;
    delay(30);
  }
  return medianFilter(samples, SAMPLE_COUNT);
}

// ---------- 预警判定与驱动 ----------
void evaluateAlarm(float h, float v) {
  float dv = h * v;  // d·v 乘积

  // 红色：立即撤离
  if (v > V_RED || dv > DV_CRIT) {
    digitalWrite(LED_BLUE,   LOW);
    digitalWrite(LED_YELLOW, LOW);
    digitalWrite(LED_RED,   HIGH);
    tone(BUZZER, 1000);  // 长鸣
    return;
  }

  // 黄色：警告
  if (v > V_YELLOW) {
    digitalWrite(LED_BLUE,  LOW);
    digitalWrite(LED_YELLOW, HIGH);
    digitalWrite(LED_RED,   LOW);
    tone(BUZZER, 800);
    delay(200);
    noTone(BUZZER);
    delay(800);
    return;
  }

  // 蓝色：关注
  if (v > V_BLUE) {
    digitalWrite(LED_BLUE,  HIGH);
    digitalWrite(LED_YELLOW, LOW);
    digitalWrite(LED_RED,   LOW);
    noTone(BUZZER);
    return;
  }

  // 安全
  digitalWrite(LED_BLUE,  LOW);
  digitalWrite(LED_YELLOW, LOW);
  digitalWrite(LED_RED,   LOW);
  noTone(BUZZER);
}

// ---------- 主程序 ----------
void setup() {
  Serial.begin(9600);
  pinMode(LED_BLUE,   OUTPUT);
  pinMode(LED_YELLOW, OUTPUT);
  pinMode(LED_RED,    OUTPUT);
  pinMode(BUZZER,     OUTPUT);

  Serial.println("=== 溪流山洪预警系统启动 ===");
  Serial.println("h(m)\tv(m/s)\tQ(m3/s)\tdv(m2/s)\tdh/dt(m/h)\tLevel");

  prevH = readDepth();
  prevTime = millis();
}

void loop() {
  unsigned long now  = millis();
  float dt_hours    = (now - prevTime) / 3600000.0; // ms → h

  float h = readDepth();
  float v = calcVelocity(h);
  float q = calcDischarge(h);
  float dhdt = (dt_hours > 0.001) ? (h - prevH) / dt_hours : 0.0;
  float dv = h * v;

  evaluateAlarm(h, v);

  // 串口输出（可接 LoRa/WiFi 模块转发）
  String level = "SAFE";
  if (v > V_RED || dv > DV_CRIT) level = "RED";
  else if (v > V_YELLOW) level = "YELLOW";
  else if (v > V_BLUE) level = "BLUE";

  Serial.print(h, 3); Serial.print("\t");
  Serial.print(v, 2); Serial.print("\t");
  Serial.print(q, 3); Serial.print("\t");
  Serial.print(dv, 3); Serial.print("\t");
  Serial.print(dhdt, 2); Serial.print("\t");
  Serial.println(level);

  prevH = h;
  prevTime = now;

  // 自适应采样：水位上涨或已有预警时加速
  float interval = (dhdt > 0.1 || level != "SAFE") ? SAMPLE_FAST : SAMPLE_NORMAL;
  delay(interval);
}
```

### 6.3 采样策略

| 工况 | 采样间隔 | 理由 |
|---|---|---|
| 正常（v < 阈值、dh/dt 平缓） | 60 秒 | 节省功耗，正常水位变化缓慢 |
| 预警状态（黄色/红色） | 5 秒 | 快速追踪变化，及时升级 |
| 降雨触发（雨量计脉冲 > 阈值） | 5 秒 | 山洪可能性增大，需密集监测 |

## 7. 校准、安装与维护

### 7.1 现场测量

部署前需完成三项实地勘测：

**（1）断面测量**

在监测断面位置，用皮尺/激光测距仪测量 b（底宽），在两侧河岸打桩记录左右边坡。天然断面可能非标准梯形，取 3–5 个特征水深点的 A-P 对建立分段函数。

**（2）底坡 S 测量**

在沿河 50–100 m 范围内，用水准仪或手持 GPS 测量上下游两点水面高程差 Δz，底坡 S = Δz / ΔL。山区溪流典型 S 在 0.005–0.05 之间。

**（3）糙率 n 查表**

参照 Chow（1959）《Open-Channel Hydraulics》第 5 章中的天然河道 n 值（节选）：

| 河道状况 | n 值范围 |
|---|---|
| 清洁、顺直、满水、无深潭或浅滩 | 0.025 – 0.033 |
| 同上，但有杂草与石块 | 0.030 – 0.040 |
| 清洁、蜿蜒、有浅潭与浅滩 | 0.033 – 0.045 |
| 多石河段、有水草 | 0.035 – 0.050 |
| 底部多砾石、大石块 | 0.040 – 0.070 |
| 杂草丛生、深潭 | 0.050 – 0.080 |
| 山区溪流、砾石/卵石/少量大石 | 0.030 – 0.050 |
| 山区溪流、大石与卵石 | 0.040 – 0.070 |

选择最接近现场描述的 n 值中位数作为初始值。

### 7.2 率定方法

多次实测对反算 n：

1. 在断面选择水流平稳时段，用浮标法或手持流速仪实测表面流速 v_surface；
2. 断面平均流速 v_obs ≈ 0.85 × v_surface（天然河道经验系数）；
3. 同步记录水深 h_obs，计算 R_obs = A(h_obs) / P(h_obs)；
4. 反算：n_cal = R_obs^(2/3) · S^(1/2) / v_obs；
5. 至少在不同水位（低水、中水、高水）各测 3 次，取均值。

```cpp
// 率定辅助代码片段
void calibrateN() {
  Serial.println("=== 率定模式 ===");
  Serial.println("输入实测水深(m)和流速(m/s)，例如: 0.50,0.85");
  // 在串口监视器输入 "0.50,0.85" 计算 n
}
```

### 7.3 维护要点

| 项目 | 周期 | 操作 |
|---|---|---|
| 超声波探头清洁 | 每周 | 清除蜘蛛网、灰尘、露水凝结 |
| 供电检查 | 每周 | 太阳能板除尘、电池电压 ≥ 11.5V |
| 断面复核 | 每季度或暴雨后 | 河床冲刷可能改变断面形状，重新测量 b、m |
| 率定复核 | 每半年 | 重新用流速仪标定 n，确认曼宁曲线未漂移 |
| 防雷接地 | 安装时 | 金属杆架设避雷针、设备加 TVS 管 |
| 冬季防冻 | 入冬前 | 气温 < 0℃ 地区回收电子设备或做保温 |

## 8. 局限性与安全声明

### 8.1 系统局限

- **单点监测**：仅测量一个断面的水位，无法感知上游正在发生的降雨或汇流。山洪波峰从上游到下游可能只有几分钟，单纯依靠本站预警的提前量极为有限。
- **曼宁公式的适用边界**：（a）均匀流假设在涨水/退水阶段不严格成立；（b）糙率 n 可能随水位变化（低水位时石块暴露，n 偏大）；（c）rating curve（水位-流量曲线）在高水位外推时精度急剧下降 —— 发生过断面漫滩或形状突变时公式可能完全失效。
- **传感器失效**：超声波在暴雨时可能因水面剧烈波动而返回错误读值；探头被落叶、漂浮物遮挡。
- **电子系统脆弱性**：野外高温、高湿、雷击、鼠咬等因素均可导致系统宕机，失效时无声。

### 8.2 安全声明

> ⚠️ 本系统是一个辅助决策工具，不是安全证书。山洪预警的黄金法则是**上游预警**：只有在上游设置雨量计 + 水位计（联动无线通信），才能为下游游泳者提供足够长（15-30 分钟以上）的撤离窗口。本系统若仅依赖本站水位，滞后效应可能使预警发出时危险已到来。

本系统不可替代以下措施：

- 有资质的救生员现场值守；
- 游泳区域的安全管理（警戒线、警示牌、准入制度）；
- 天气预报与山洪预警信息的主动获取；
- 游泳者自身的安全意识与判断。

**部署建议**：将本系统作为多级预警体系的底层终端之一，与上游雨量-水位遥测站联动，构成完整的山洪预警链。

## 9. 参考文献

1. Manning, R. (1891). *On the flow of water in open channels and pipes*. Transactions of the Institution of Civil Engineers of Ireland, 20, 161–207.
2. Chow, V. T. (1959). *Open-Channel Hydraulics*. McGraw-Hill, New York. （第 5 章：糙率 n 值表；第 7 章：均匀流）
3. Chézy, A. (1769). 关于渠道流速公式的原始报告，收录于 Clemens, H. & Herschel, C. (1897).
4. Henderson, F. M. (1966). *Open Channel Flow*. Macmillan, New York.
5. Rantz, S. E. et al. (1982). *Measurement and Computation of Streamflow: Volume 1. Measurement of Stage and Discharge*. USGS Water-Supply Paper 2175.
6. Rescate, S. (2014). *Whitewater Rescue Manual: Techniques for River Rescue*. International Rescue Instructors Alliance. （有关 d·v 乘积的人身稳定性准则）
7. Jonkman, S. N. & Penning-Rowsell, E. (2008). *Human Instability in Flood Flows*. Journal of the American Water Resources Association, 44(5), 1208–1218.
8. Texas Electronics Inc. (2020). *YF-S201 Hall Effect Water Flow Sensor Datasheet*.
9. Cytron Technologies (2019). *HC-SR04 Ultrasonic Ranging Module User's Manual*.
10. 中国水利部水文局. (2015). *山洪灾害监测预警系统技术规范*（SL 675-2014）. 中国水利水电出版社.

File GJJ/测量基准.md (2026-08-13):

# 测量基准 (LouisGJJ 项目)

日期：2026-08-13
单位：mm（Tinkercad/STL 默认毫米）

## 一、传感器及硬件尺寸

| 名称 | 高 | 宽 | 长 | 备注 |
|---|---|---|---|---|
| 显示屏 | 16.8 | 36.0 | 79.9 | |
| Arduino | 12.6 | 53.3 | 68.8 | |
| 风杯 | 4.7（厚） | — | — | 底面直径 63.4，外置安装 |
| 温湿度传感器 | 7.6 | 26.3 | 35.4 | |
| 土壤湿度传感器 | 7.9 | 18.2 | 10.36 | |
| 水流传感器 | 22.1 | 39.7 | 64.8 | |
| 面包板 | 10.2 | 54.7 | 82.8 | |

## 二、STL 模型尺寸（实测包围盒）

| 文件 | 三角形数 | 高 | 宽 | 长 | 备注 |
|---|---|---|---|---|---|
| Sizzling Jaban.stl | 1946 | 11.00 | 11.00 | 35.65 | |
| Sizzling Jaban (1).stl | 8024 | 89.00 | 80.00 | 176.37 | |
| Sizzling Jaban (2).stl | 8024 | 89.00 | 80.00 | 176.37 | 与 (1) 尺寸相同但文件内容不同 |
| Terrific Trug.stl（小） | 1412 | 13.12 | 29.87 | 74.67 | 旧版小模型 |
| Terrific Trug (1).stl | 2256 | 154.00 | 123.56 | 178.41 | 即仓库 GJJ/Terrific Trug.stl |
| Terrific Trug (2).stl | 1040 | 184.80 | 148.30 | 214.10 | 120% 版，即 LouisGJJ.stl |
| Terrific Trug (3).stl | 1040 | 160.64 | 128.91 | 186.11 | 104.3% 版 |

## 三、Terrific Trug 内部腔体（(1) 版实测）

| 位置 | 高 | 宽 | 长 |
|---|---|---|---|
| 外尺寸 | 154.00 | 123.56 | 178.41 |
| 内腔（顶部开口） | 146.0 | 69.5 | 132.0 |
| 底部台阶区（z<13mm） | 13.0 | 111.5 | 157.1 |
| 壁厚 | 10~12 mm | | |

120%（LouisGJJ.stl）时内腔：高 175.2 / 宽 83.4 / 长 158.4

## 四、装配结论

- 方案：风杯外置，其余 6 件（显示屏、Arduino、温湿度、土壤湿度、水流传感器、面包板）全部装进内腔
- 100% 可装但偏挤（底层 122.5×64.8 vs 内腔 132×69.5），建议 120%
- 三层分法：底座 0-30mm（面包板+水流）、中层 30-90mm（Arduino+温湿度）、上层 90-154mm（显示屏+土壤湿度）
- Bambu Lab P1S（256³ 打印体积，PLA）：最大缩放 143.5%（高 221.0 / 宽 177.3 / 长 256.0），120% 完全可打

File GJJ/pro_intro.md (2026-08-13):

Have you ever encounter big waves when you are swimming in ocean and lakes that have no safety infrastructures but are fun? If not, then please listen to my story. Last year, me and my family experience a landslide when we are swimming in a lake that is unplanned. At last, we luckily survived ,but the scene that the rock falls down and rolling towards us is still visible and vivid in my mind. So, yes, this is why we decided to make this product, we planned to solve the problem that people face natural disaster when swimming in water areas that are fun but not too safe, we also encourage people to embrace the nature. Our slogan is “Let’s get lost where Google Map can’t find us.”, this shows that we really want people to have fun in nature without scruple. Basically, we used a lot of sensor, for example soil moisture monitor, anemometer, hydrometric propeller… The basic use of them is to forecast and detect flood ,debris flow and landslides.

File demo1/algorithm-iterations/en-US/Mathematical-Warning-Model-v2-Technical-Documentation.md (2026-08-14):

# Mathematical Warning Model · v2 Technical Documentation

**Version:** v2 (second release)
**Algorithm name:** Sensor-calibrated + fast sliding baseline warning model
**Date:** 2026-08-14

---

## 1. Changes from v1

| Item | v1 | v2 | Reason |
|---|----|----|---|
| Level naming | 1 = Level-3 / 3 = Level-1 (Level-1 most severe) | **0 = Normal / 1 = Level 1 / 2 = Level 2 / 3 = Level 3 (Level 3 most severe)** | Standardized level system: larger number = more severe, maximum is Level 3 |
| Debris-flow weights | 0.40S+0.30Q+0.20dQ+0.10ΔS | **0.30S+0.35Q+0.20dQ+0.15ΔS** | Soil saturates easily and used to dominate the score, weight lowered; flow (flash-flood signal) raised to the highest weight |
| Q_MAX (full-channel flow) | 30 L/min | **3 L/min** | Aligned with YF-S401 measured range (measured max ~1.7) |
| DQ_MAX (change-rate cap) | 5 L/min/s | **0.5 L/min/s** | Measured per-second jumps ~0.3 |
| Spike fallback threshold | 2.0 | **0.5** | Same as above; lets flow data truly participate in inference |
| Sliding-baseline cold start | 2 hours | **15 minutes** | Adapts to local climate faster |
| Flash-flood independent path F | 0.6Q̄+0.4dQ̄ | Retained | Flow surge triggers independently, not gated by soil threshold |
| LCD display | None | **Wind / soil moisture / flow / warning level** | On-site visualization |
| Flow pulse diagnostics | Single-edge counting | **Rising/falling edges counted separately + D8 level** | Quickly locate wiring/edge-direction problems |

---

## 2. Algorithm Structure (v2)

```
Final level = max(Debris flow D, Flash flood F, Wind, Flow spike, Surge, Soil saturation)   ← 0~3
```

**Level definitions (larger number = more severe):**

| Level | Meaning | Example trigger |
|---|---|---|
| 0 | Normal | All factors below thresholds |
| 1 | Level-1 warning (mildest) | D/F ≥ 0.45, or wind ≥ 25 km/h, or surge |
| 2 | Level-2 warning | D/F ≥ 0.55, or wind ≥ 40 km/h, or spike ≥ P95 |
| 3 | Level-3 warning (most severe) | D/F ≥ 0.75, or wind ≥ 60 km/h |

### 2.1 Debris Flow Path

```
D = 0.30 × S̄ + 0.35 × Q̄ + 0.20 × dQ̄ + 0.15 × ΔS̄
```

- Path skipped while soil < 60% (unsaturated) — flash flood / wind paths are **not** gated
- **Special rules:** soil above local P90 + rising flow + 5-min continuous rise → Level 3 directly; soil above local P90 + flow ≥ 70% of channel capacity → Level 2; soil 10-min rise ≥ 20% → at least Level 1

### 2.2 Flash Flood Path (independent index)

```
F = 0.60 × Q̄ + 0.40 × dQ̄
```

- **Not gated by the soil threshold** — triggers on flow surge alone
- Acts as a flow-based approximation of the 70% Manning component (this scheme does not use an ultrasonic water-level sensor — water level overlaps with flow rate functionally, flow is the core)

### 2.3 Wind Path

| Wind speed | Level |
|---|---|
| ≥ 25 km/h | Level 1 |
| ≥ 40 km/h | Level 2 |
| ≥ 60 km/h | Level 3 |

### 2.4 Flow Spike Path

- Per-second flow change rate above local historical P95 → **Level 2**; ≥ 0.8 normalized → **Level 1**

### 2.5 Surge Path (second-level response)

| Surge | Trigger |
|---|---|
| Soil rises ≥ 20% within 5 s | Level 1 immediately |
| Wind rises ≥ 12 km/h within 60 s | Level 1 immediately |

### 2.6 Soil Saturation Path (new in v2)

Soil ≥ 85% or above local P90 → **at least Level 1** (saturated soil is itself a hazard, independent of flow; persists until soil drops)

### 2.7 Hysteresis Hold (new in v2, debounce)

- Upgrade: takes effect immediately and is held
- Downgrade: only after the hold time — Level 1: 10 s / Level 2: 15 s / Level 3: 20 s
- Prevents level flickering from single-point jitter / momentary drops

---

## 3. Sliding Baseline (v2 adjustments)

- **Window:** 24 h, sampled once per minute; current value mapped to the local [P10, P95] range → 0~1 relative position
- **Cold start shortened to 15 minutes:** baseline activates after 15 min of data; the previous 2-hour wait is removed
- **Fallback when data insufficient (absolute values, aligned to sensor range):** Qn = flow/3, dQn = change-rate/0.5

---

## 4. LCD Display (new in v2)

- **Hardware:** I2C LCD 1602 (SCL→A5, SDA→A4, address 0x27)
- **Displayed content (ASCII, refreshed every second):**

```
W12.3 S45% F0.50     ← wind km/h · soil moisture % · flow L/min
ALARM:3 L3           ← warning level 0~3 (0=normal, 3=most severe)
```

- Wind and warning level are pushed from the server (server.py) over serial (protocol `D<wind>,<level>`); soil moisture and flow are read locally by the Arduino

---

## 5. Strengths

1. **Flow data truly participates in inference:** after calibration parameters are aligned with the sensor range, Q̄/dQ̄ change from "squashed mosquito legs" into effective factors; the flash-flood path responds to real flow changes
2. **Sliding baseline activates quickly:** 15-min cold start — self-adapts to local climate a quarter hour after power-on
3. **Standardized level system:** 0~3, larger number = more severe; LCD/web/docs use a consistent convention (Level 3 = highest)
4. **On-site visualization:** LCD shows the four core data streams in real time, observable without a computer/web page
5. **Diagnostics:** dual-edge pulse counting + level output — wiring/signal problems located within 30 s
6. Retains all v1 advantages: independent multi-paths, simple and explainable, cold-start capable

---

## 6. Limitations

1. **Flow sensor range still narrow:** YF-S401 measured 0.05~3 L/min; real flood flows far exceed this — calibration parameters serve the current test environment (pump + pipe) and must be recalibrated when the environment changes
2. **Wind data depends on an external computer** (192.168.1.200:8001): when that service is offline the wind path is disabled (LCD wind shows 0)
3. **15-min sliding baseline may still be unstable:** under sudden weather, the first 15 minutes of baseline are low quality; absolute fallback precision is limited
4. **Surge thresholds remain empirical** (soil +20%/5 s, wind +12 km/h/60 s), not statistically calibrated
5. **LCD is ASCII-only:** cannot display Chinese; field staff must learn the 0~3 number meanings
6. **Hard level thresholds:** 0.45/0.55/0.75 step jumps with no confidence/persistence check (single-point jitter may cause false alarms)

---

## 7. Characteristics

1. **Real-time:** recomputed every second + LCD refreshed every second + web page refreshed every 0.5 s
2. **Dual-end display:** web page (full metrics) + LCD (core on-site metrics)
3. **Calibratable parameters:** Q_MAX/DQ_MAX/spike threshold come from measurements, not guesses
4. **Modular:** 5 independent paths, each can be iterated separately later

---

## 8. Version Plan

- **v2.x candidates:** calibrate surge thresholds from historical distribution (replacing empirical values); ~~add persistence check (trigger only after N consecutive seconds above threshold, debounce)~~ — implemented: hysteresis hold (Level 1: 10 s / Level 2: 15 s / Level 3: 20 s)
- **v3 candidates:** wind sensor onboard (sensor migrated to the integrated board, removing external-computer dependency); LCD shows flash-flood F / debris-flow D values

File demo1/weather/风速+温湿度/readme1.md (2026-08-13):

# 风速 + 温湿度监测与预警系统（readme1）

## 这个项目做了什么

本项目由 **Arduino UNO + 三杯式风速传感器 + DHT11 温湿度传感器** 组成，实现：

1. **实时监测**：同时采集风速（km/h）、温度（℃）、湿度（%）
2. **风速报警**：风速超过 10 km/h 时板载 LED 闪烁报警（Arduino 端）
3. **电脑端可视化**：网页仪表盘实时显示风速曲线、温湿度曲线、阵风值、30 分钟平均基准线
4. **智能预警**：根据 8 条气象加分规则计算当前得分，达到阈值自动分级预警（一级/二级/三级），页面横幅警示 + 提示音
5. **数据转发接口**：8001 端口提供 JSON 接口（`/wind`），其他电脑的综合监控系统可以直接调用

## 目录结构

```
风速+温湿度/
├── 02_WindTempHumidity.ino   ← Arduino 主程序（烧录到开发板）
├── readme1.md                ← 本说明文档
└── server/                   ← 电脑端服务器（Python + Node.js 双服务）
    ├── wind_server.py        ← 8001 转发服务（Python）：独占串口，解析数据并转发 JSON
    ├── server.js             ← 仪表盘服务器：轮询 8001 拿数据 + 加分预警引擎 + 网页推送
    ├── read_serial.js        ← 串口调试工具（读 N 秒原始数据）
    ├── package.json / package-lock.json
    ├── 启动仪表盘.bat         ← 双击启动（自动先起 8001 转发，再起仪表盘）
    └── public/index.html     ← 仪表盘网页（前端）
```

## 架构说明（两个服务分工）

```
Arduino (COM3 串口, 9600)
   │
   ▼
wind_server.py  ── 独占串口，解析 CSV/文本，缓存最新值
   │               HTTP :8001/wind  →  {"wind_kmh":..,"wind_ms":..,"temp":..,"hum":..,"time":..}
   ▼
server.js  ── 每 1 秒轮询 8001 转发接口（不再直接占串口）
   │        加分预警引擎 + SSE 推送
   ▼
浏览器 http://localhost:3000（仪表盘网页）
```

> 为什么要这样分：Windows 串口是独占的，多个程序不能同时读 COM3。
> 8001 转发服务（wind_server.py）独占串口，仪表盘（server.js）和其他电脑都通过 HTTP 接口取数据，互不冲突。

## 硬件接线

| 风速传感器 | Arduino UNO |
| --- | --- |
| 红线 | A0 |
| 黑线 | GND |

| DHT11（背面标 s/v/g） | Arduino UNO |
| --- | --- |
| v（VCC） | 5V |
| s（DATA） | D4（没有 D4 可换任意空闲数字脚，改代码 DHTPIN） |
| g（GND） | GND |

## 使用步骤

### 1. 烧录 Arduino 程序
- Arduino IDE 打开 `02_WindTempHumidity.ino`
- 安装库：工具 → 管理库 → 搜索 "DHT sensor library"（Adafruit）
- 选择 Arduino Uno 和对应 COM 口，点上传

> ⚠️ **上传代码前必须先关闭 8001 转发服务**（wind_server.py 独占串口，占着会导致上传报 "cannot open port 拒绝访问"）。仪表盘 server.js 不占串口，不用关。

### 2. 启动服务器（两种方式任选）

**方式 A：双击 `启动仪表盘.bat`**（会自动先启动 8001 转发，再启动仪表盘）

**方式 B：命令行手动启动**
```bash
cd server
python wind_server.py    # 第一个窗口：8001 转发服务
node server.js           # 第二个窗口：仪表盘（或 npm install 后 npm start）
```

浏览器打开 http://localhost:3000

### 3. 其他电脑调用数据接口

局域网内其他电脑（如综合监控系统）直接访问：

```
http://<本机IP>:8001/wind
```

返回 JSON：
```json
{"wind_ms": 2.86, "wind_kmh": 10.3, "time": "16:17:00", "temp": 35.3, "hum": 37.0}
```

- `wind_kmh`：风速 km/h，`wind_ms`：风速 m/s
- `temp`：温度 ℃，`hum`：湿度 %（串口输出 CSV 时才有；文本格式时为 null）
- 串口断线会自动重连（每 5 秒重试）

## Arduino 程序功能（02_WindTempHumidity.ino）

- 风速：ADC → 电压（V）→ 风速（km/h），每 0.2 秒更新
- 温湿度：DHT11 每秒读取一次（太快会读失败）
- 报警：风速 > 10 km/h → 引脚 13 LED 闪烁（不阻塞主循环）
- 串口输出 CSV：`电压,风速,温度,湿度`（波特率 9600）

## 加分预警规则（server.js 实现）

**基准线** = 最近 30 分钟平均风速（黄色虚线画在风速曲线上）
**阵风** = 最近 3 秒内最大风速

| 条件 | 加分 |
| ---- | ---- |
| 阵风骤增：2分钟平均 ≥ 基线的2倍 且 阵风 ≥ 5 m/s | +3 |
| 静风后突风：平均风速 < 1.5 m/s 且 阵风 ≥ 4 m/s | +2 |
| 大风：阵风 ≥ 5 m/s | +2 |
| 温度骤降：现在比 15 分钟前低 5℃ | +2 |
| 湿度骤升：10分钟均值比一小时前提升 ≥ 15% | +2 |
| 湿度高且突然上升：湿度 ≥ 80% 且 一小时内提升 ≥ 15% | +3 |
| 湿度接近饱和：湿度 ≥ 90% | +1 |
| 露点贴近气温：气温 − 露点 ≤ 2℃ 且 湿度 ≥ 70% | +2 |

**预警级别**：得分 ≥ 4 一级，≥ 6 二级，≥ 8 三级

> 得分 = 当前满足条件的分值合计（每项最多算一次）。涉及"15分钟前/一小时前"的规则需要数据积累到对应时长后才会激活。

## 仪表盘功能

- 大字显示：风速 / m/s / 阵风 / 基准线 / 电压 / 温度 / 湿度 / 收到数据数
- 风速曲线（青线 + 黄色虚线基准线）
- 温湿度曲线（橙线温度、蓝线湿度，双轴刻度）
- 得分徽章 + 预警横幅（一级黄 / 二级橙 / 三级红闪烁），升级时响提示音
- 加分规则明细表：8 条规则实时状态（✅触发/○未触发、当前值 vs 门槛），附总分
- 数据来源：轮询 8001 转发接口（每 1 秒一次），转发服务掉线会自动重连

## 项目参考图片

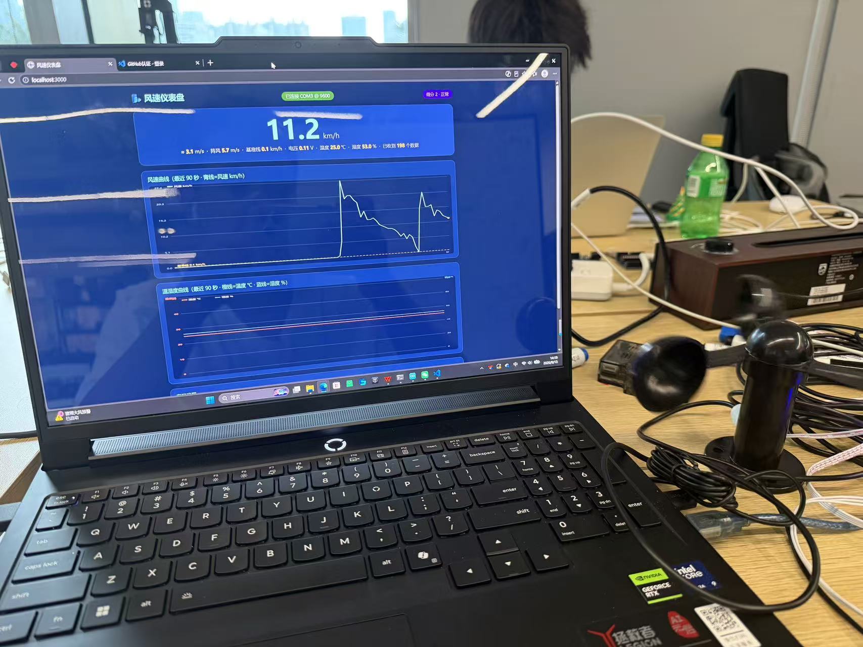
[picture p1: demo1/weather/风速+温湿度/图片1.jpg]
项目图片1


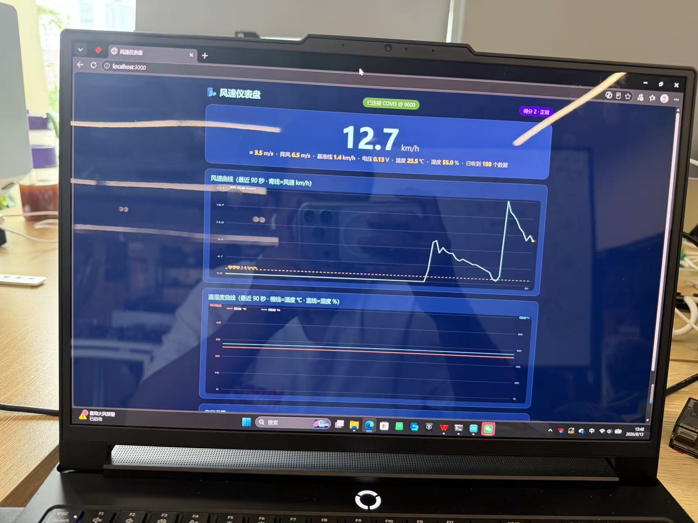
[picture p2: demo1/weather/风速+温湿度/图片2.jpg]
项目图片2


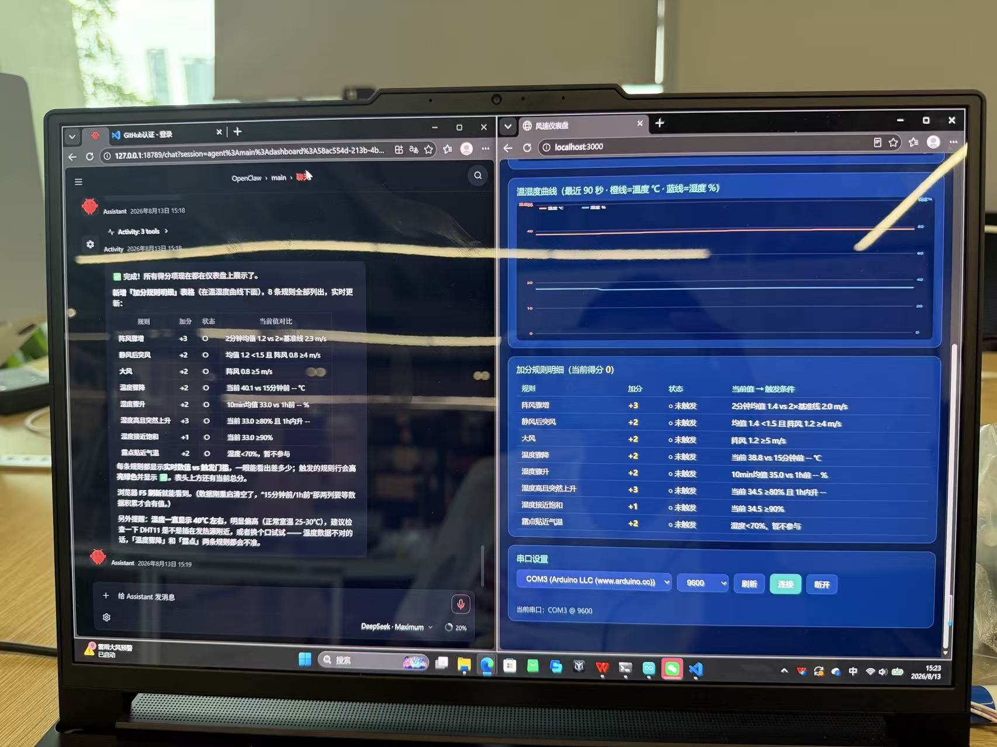
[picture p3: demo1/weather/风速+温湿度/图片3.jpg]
项目图片3


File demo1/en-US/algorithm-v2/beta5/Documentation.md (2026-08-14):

# Atmosphere Demo 1 Documentation (beta5 · Algorithm v2, first archive)

## 1. Project Overview

Atmosphere is a smart flash-flood & debris-flow monitoring and early-warning system for outdoor streams / drifting sites.

beta5 is the **first archive of Algorithm v2**: built on beta4, it adds an on-site LCD display, upgrades the model to v2 (sensor-calibrated + fast sliding baseline + hysteresis hold + soil-saturation rule), and integrates wind data over the network.

## 2. Hardware Wiring

Controller: Arduino Nano (ATmega328P, new bootloader)

- Soil moisture: AO→A2 (analog), DO→D2 (digital/disconnect detect), VCC→5V, GND→GND
- Flow sensor YF-S401: red→5V, yellow→D8 (signal), black→GND
- Pump: IO→D9 (PWM pin, soft-start/speed; higher duty = faster pumping); independent power supply recommended (common ground only)
- Temp/humidity DHT11: v→5V, s→D4, g→GND (requires DHT sensor library)
- LCD 1602 (I2C): SCL→A5, SDA→A4, address 0x27 (try 0x3F if blank)
- Wind sensor (cup anemometer, 0~5V): on another computer's Arduino UNO A0, forwarded via HTTP 8001

## 3. Software Implementation

Two files (both included in this folder):

**FlowSensor.ino** — Arduino firmware (serial **115200**, one JSON line per second):
- Three data paths: soil moisture (with disconnect detection), flow (YF-S401 pulse counting), temp/humidity (DHT11)
- Pump PWM speed control + soft start (0→255, ~0.5 s smooth ramp); D7 pulled low as a failsafe
- Flow pulses counted on **rising and falling edges separately + D8 level output** (diagnose edge direction / wiring)
- LCD: line 1 `W12.3 S45% F0.50` (wind km/h · soil % · flow L/min), line 2 `ALARM:3 L3` (warning level 0~3)
- LCD data pushed from the server over serial via the **D-line protocol**: `D<wind km/h>,<level>\n` (e.g. `D12.3,2`)

**server.py** — Python web service (port 8080):
- Serial reading + wind HTTP integration (polls `http://192.168.1.200:8001/wind`) + v2 warning model + web page (pump slider, four cards + charts + warning card)
- `lcd_sender` thread: pushes the D line (wind + current level) to the Arduino every second
- Web page metrics: debris D / flood F / soil S / flow Q / dQ / ΔS / spike risk / wind risk

## 4. Warning Model (Algorithm v2)

**Level system (larger number = more severe): 0 = Normal / 1 = Level 1 / 2 = Level 2 / 3 = Level 3 (highest)**

```
Final level = max(Debris flow D, Flash flood F, Wind, Flow spike, Surge, Soil saturation)   ← 0~3
```

**Debris-flow path:**

```
D = 0.30·S̄ + 0.35·Q̄ + 0.20·dQ̄ + 0.15·ΔS̄
```

- Gate: path skipped while soil < 60% (unsaturated) — flash flood / wind are not gated
- Thresholds: D ≥ 0.75 → Level 3; ≥ 0.55 → Level 2; ≥ 0.45 → Level 1
- Special rules: soil above local P90 + rising flow + 5-min continuous rise → Level 3 directly; soil above local P90 + flow ≥ 70% of capacity → Level 2; soil 10-min rise ≥ 20% → at least Level 1

**Flash-flood path (independent index):**

```
F = 0.60·Q̄ + 0.40·dQ̄
```

- Not gated by the soil threshold — triggers on flow surge alone; same thresholds (0.45/0.55/0.75)
- Flow-based approximation of the 70% Manning component (ultrasonic water-level plan dropped; flow is the core)

**Wind path:** ≥25 km/h → Level 1; ≥40 km/h → Level 2; ≥60 km/h → Level 3

**Flow-spike path:** per-second change rate above local historical P95 → Level 2; normalized ≥ 0.8 → Level 1 (fallback when baseline insufficient: rate ≥ 0.5 L/min/s = full scale)

**Surge path (second-level response):** soil rises ≥ 20% within 5 s / wind rises ≥ 12 km/h within 60 s → Level 1 immediately

**Soil-saturation path (new in v2):** soil ≥ 85% or above local P90 → at least Level 1 (saturated soil is itself a hazard, independent of flow)

**Hysteresis hold (new in v2):** level upgrades take effect immediately and are held; downgrades only after the hold time — Level 1: 10 s / Level 2: 15 s / Level 3: 20 s (debounce)

**Sliding baseline:** 24 h window sampled once per minute; current value mapped onto the local [P10, P95] → 0~1; **cold start 15 minutes**; fallback to absolute values when insufficient (Qn=flow/3, dQn=rate/0.5)

## 5. How to Run

1. Compile and upload FlowSensor.ino to the Arduino Nano (serial monitor at **115200**)
2. Run `python3 -u server.py`
3. Open `http://localhost:8080` in a browser; drag the slider to control pump speed
4. Keep the wind service `http://192.168.1.200:8001/wind` online

## 6. Version Status

beta5 is the **first archive of Algorithm v2**: after Demo 1 ended, development moved to the algorithm-iteration phase (warning model v1→v2; docs under `demo1/algorithm-iterations/`). The ultrasonic water-level plan is dropped (overlaps with the flow sensor; no Manning 70%).

## 7. Known Issues

- Wind data depends on an external computer (192.168.1.200:8001); when offline, the wind path is disabled and LCD wind shows 0 — physical migration to the integrated board is a follow-up item
- Narrow flow-sensor range (YF-S401 measured 0.05~3 L/min); calibration serves the current test environment and must be redone if it changes
- Surge thresholds remain empirical (soil +20%/5 s, wind +12 km/h/60 s), not statistically calibrated
- LCD is ASCII-only; cannot display Chinese; field staff must learn the 0~3 level meanings

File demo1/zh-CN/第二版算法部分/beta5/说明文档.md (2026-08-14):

# Atmosphere Demo 1 说明文档（beta5 · 算法 v2 第一版归档）

## 一、项目简介

Atmosphere 是面向野外溪流/漂流点的山洪 + 泥石流智能监测预警系统。

beta5 为**第二版算法（v2）**的第一版归档：在 beta4 基础上新增 LCD 现场显示、算法升级到 v2（传感器标定对齐 + 快速滑动基准 + 滞回保持 + 土壤饱和规则），并接入风速网络数据。

## 二、硬件连接方式

主控：Arduino Nano（ATmega328P，新 Bootloader）

- 土壤湿度传感器：AO→A2（模拟量），DO→D2（数字/断线检测），VCC→5V，GND→GND
- 流速传感器 YF-S401：红线→5V，黄线→D8（信号），黑线→GND
- 水泵：IO 接 D9（PWM 脚，软启动/调速，占空比越大抽水越快）；建议独立供电（只共地）
- 温湿度 DHT11：v→5V，s→D4，g→GND（需 DHT sensor library）
- LCD 1602（I2C）：SCL→A5，SDA→A4，地址 0x27（屏不亮改 0x3F）
- 风速传感器（三杯式，0~5V）：接另一台电脑的 Arduino UNO A0，经 HTTP 8001 转发到本机

## 三、软件实现

两个文件（均已放入本文件夹）：

**FlowSensor.ino** —— Arduino 固件（串口 **115200**，每秒输出一行 JSON）：
- 三路采集：土壤湿度（带断线检测）、流速（YF-S401 脉冲计数）、温湿度（DHT11）
- 水泵 PWM 调速 + 软启动（0→255 约 0.5 秒平滑升降），D7 拉低兜底防误开
- 流速脉冲**上升沿/下降沿分开计数 + D8 电平输出**（诊断沿方向/接线问题）
- LCD 显示：行 1 `W12.3 S45% F0.50`（风速 km/h · 土湿度 % · 流速 L/min），行 2 `ALARM:3 L3`（预警等级 0~3）
- LCD 数据由服务端串口下发，**D 行协议**：`D<风速km/h>,<预警等级>\n`（如 `D12.3,2`）

**server.py** —— Python Web 服务（端口 8080）：
- 串口读取 + 风速 HTTP 集成（轮询 `http://192.168.1.200:8001/wind`）+ v2 预警模型 + 网页（水泵滑块、四卡 + 曲线 + 预警卡）
- `lcd_sender` 线程：每秒向 Arduino 下发 D 行（风速 + 当前等级）
- 网页显示：泥石流 D / 山洪 F / 土壤 S / 流量 Q / 突变 dQ / 土湿涨 ΔS / 尖峰风险 / 风速风险

## 四、预警模型（算法 v2）

**等级体系（数字越大越严重）：0 = 正常 / 1 = 一级 / 2 = 二级 / 3 = 三级（最高）**

```
最终等级 = max(泥石流 D, 山洪 F, 风速, 流量尖峰, 突变, 土壤饱和)   ← 0~3
```

**泥石流路径：**

```
D = 0.30·S̄ + 0.35·Q̄ + 0.20·dQ̄ + 0.15·ΔS̄
```

- 门槛：土壤 < 60%（未饱和）时跳过本路径（山洪/风速不受限）
- 阈值：D ≥ 0.75 → 三级；≥ 0.55 → 二级；≥ 0.45 → 一级
- 特殊规则：土壤超当地 P90 + 流量上涨 + 5 分钟持续上升 → 直接三级；土壤超当地 P90 + 流量 ≥ 70% 满槽 → 二级；土壤 10 分钟涨幅 ≥ 20% → 至少一级

**山洪路径（独立指数）：**

```
F = 0.60·Q̄ + 0.40·dQ̄
```

- 不受土壤门槛限制，流量暴涨即触发；阈值同上（0.45/0.55/0.75）
- 曼宁公式 70% 分量的流量近似替代（超声波水位方案已砍掉，流速为核心）

**风速路径：** ≥25 km/h → 一级；≥40 km/h → 二级；≥60 km/h → 三级

**流量尖峰路径：** 秒级变化率超当地历史 P95 → 二级；归一化 ≥ 0.8 → 一级（基准不足回退：变化率 ≥ 0.5 L/min/s = 满刻度）

**突变路径（秒级响应）：** 土壤 5 秒内涨 ≥20% / 风速 60 秒内涨 ≥12 km/h → 立即一级

**土壤饱和路径（v2 新增）：** 土壤 ≥85% 或超当地 P90 → 至少一级（土体饱和本身就是危险，不依赖流量）

**滞回保持（v2 新增）：** 升级立即生效并保持；降级需超过保持时间——一级 10 秒 / 二级 15 秒 / 三级 20 秒（防抖）

**滑动基准：** 24 小时窗口每分钟采样，当前值映射到当地 [P10,P95] → 0~1；**冷启动 15 分钟**；数据不足回退绝对值（Qn=flow/3、dQn=变化率/0.5）

## 五、运行方式

1. 编译上传 FlowSensor.ino 到 Arduino Nano（串口监视器选 **115200**）
2. 运行 `python3 -u server.py`
3. 浏览器打开 `http://localhost:8080`；拖滑块调节水泵速度
4. 保持风速服务 `http://192.168.1.200:8001/wind` 在线

## 六、版本状态

beta5 为**算法 v2 的第一版归档**：Demo 1 完结后进入算法迭代阶段（数学预警模型 v1→v2，文档见 `demo1/algorithm-iterations/`）；超声波水位方案已砍掉（与流速功能重叠，不做曼宁 70%）。

## 七、已知问题

- 风速数据依赖外部电脑（192.168.1.200:8001），该服务离线时风速路径失效、LCD 风速显示 0——物理迁移到综合板为后续项
- 流量计量程窄（YF-S401 实测 0.05~3 L/min），标定参数为当前测试环境服务，换环境需重新标定
- 突变阈值仍为经验值（土壤 5s+20%、风速 60s+12km/h），未做统计标定
- LCD 仅 ASCII，无法显示中文，现场人员需熟悉 0~3 等级含义

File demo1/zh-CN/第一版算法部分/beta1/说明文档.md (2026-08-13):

# Atmosphere Demo 1 说明文档（第一版）

## 一、项目简介

Atmosphere 是面向野外溪流/漂流点的山洪 + 泥石流智能监测预警系统。

Demo 1 实现：土壤湿度、流速、风速三路环境采集 + 水泵控制 + Web 实时监控 + 预警数学模型。

## 二、硬件连接方式

主控：Arduino Nano（ATmega328P，新 Bootloader）

土壤湿度传感器：AO→A2（模拟量），DO→D2（数字/断线检测），VCC→5V，GND→GND

流速传感器 YF-S401：红线→5V，黄线→D8（信号），黑线→GND

水泵：接 D7（高电平抽水，低电平停止）

风速传感器（三杯式，0~5V）：接另一台电脑的 Arduino UNO A0，经 HTTP 转发到本机

## 三、软件实现

两个文件（均已放入本文件夹）：

FlowSensor.ino —— Arduino 固件：三路采集 + 水泵控制，每秒输出一行 JSON 到串口（9600）

server.py —— Python Web 服务（端口 8080）：串口读取 + 风速 HTTP 集成 + 预警模型 + 网页

串口命令（单字节）：发送 1 开泵 / 0 关泵。

风速接口：对方电脑 http://192.168.1.200:8001/wind 返回 JSON（wind_ms / wind_kmh / temp / hum）。

## 四、预警模型

泥石流（已完整落地）：

危险指数 D = 0.40·S̄ + 0.30·Q̄ + 0.20·dQ̄ + 0.10·ΔS̄

S̄ 土壤湿度归一化，Q̄ 流量归一化，dQ̄ 流量突变，ΔS̄ 土壤湿度涨幅

特殊规则：土壤高湿 + 流量连涨 → 拉高等级

山洪（部分落地）：

曼宁公式 70%（缺超声波水位传感器，暂未落地）

尖峰检测 30%（用流量秒级变化率近似，阈值待标定）

滑动基准（自适应气候）：

24 小时滑动窗口，用 P10/P95 分位数判断「偏离当地正常多少」，数据积累 2 小时后生效。

预警档位（一级最严重）：

🟢 正常：D < 0.30

🟡 三级预警：0.30 ≤ D < 0.55

🟠 二级预警：0.55 ≤ D < 0.75

🔴 一级预警：D ≥ 0.75

## 五、运行方式

编译上传 FlowSensor.ino 到 Arduino Nano

运行 python3 -u server.py

浏览器打开 http://localhost:8080 查看监控页面

## 六、已知问题

水泵从 Arduino 取电会导致供电不稳、USB 反复断电复位（自己开关）——需改独立供电

山洪曼宁 70% 缺超声波水位传感器，待补

尖峰检测阈值待实测标定

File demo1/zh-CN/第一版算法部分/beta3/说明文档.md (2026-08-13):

# Atmosphere Demo 1 说明文档（第三版）

## 一、项目简介

Atmosphere 是面向野外溪流/漂流点的山洪 + 泥石流智能监测预警系统。

Demo 1 实现：土壤湿度、流速、风速三路环境采集 + 水泵 PWM 调速控制 + Web 实时监控 + 预警数学模型。

## 二、硬件连接方式

主控：Arduino Nano（ATmega328P，新 Bootloader）

土壤湿度传感器：AO→A2（模拟量），DO→D2（数字/断线检测），VCC→5V，GND→GND

流速传感器 YF-S401：红线→5V，黄线→D8（信号），黑线→GND

水泵：IO 接 D9（PWM 脚，软启动/调速，占空比越大抽水越快）；VCC/GND 接电源，D7 已拉低兜底

风速传感器（三杯式，0~5V）：接另一台电脑的 Arduino UNO A0，经 HTTP 转发到本机

## 三、软件实现

两个文件（均已放入本文件夹）：

FlowSensor.ino —— Arduino 固件：三路采集 + 水泵 PWM 调速（软启动），每秒输出一行 JSON 到串口（9600）

server.py —— Python Web 服务（端口 8080）：串口读取 + 风速 HTTP 集成 + 预警模型 + 网页（含水泵滑块调速 + 功率显示）

串口命令：发送速度值 0~255 + 换行（0 = 停止，255 = 全速）。

水泵调速：D9 PWM + 软启动（0→255 约 0.5 秒平滑升/降，抹平启动电流冲击）。

网页滑块：0~100% 拖动实时调速（150ms 防抖）；功率 = 占空比 × 满载功率（默认 1.25W 估算，可标定）。

风速接口：对方电脑 http://192.168.1.200:8001/wind 返回 JSON（wind_ms / wind_kmh / temp / hum）。

## 四、预警模型

泥石流（已完整落地）：

危险指数 D = 0.40·S̄ + 0.30·Q̄ + 0.20·dQ̄ + 0.10·ΔS̄

S̄ 土壤湿度归一化，Q̄ 流量归一化，dQ̄ 流量突变，ΔS̄ 土壤湿度涨幅

门槛：土壤湿度 < 60%（土体未饱和）直接判安全，不参与 D 分级

特殊规则：土壤高湿 + 流量连涨 → 拉高等级

山洪（部分落地）：

曼宁公式 70%（缺超声波水位传感器，暂未落地）

尖峰检测 30%（用流量秒级变化率近似，阈值待标定）

滑动基准（自适应气候）：

24 小时滑动窗口，用 P10/P95 分位数判断「偏离当地正常多少」，数据积累 2 小时后生效。

预警档位（一级最严重）：

🟢 正常：D < 0.45（土壤湿度 < 60% 时直接安全）

🟡 三级预警：0.45 ≤ D < 0.55

🟠 二级预警：0.55 ≤ D < 0.75

🔴 一级预警：D ≥ 0.75

## 五、运行方式

编译上传 FlowSensor.ino 到 Arduino Nano

运行 python3 -u server.py

浏览器打开 http://localhost:8080 查看监控页面，拖滑块调节水泵速度

## 六、已知问题

水泵从 Arduino 取电，高速时电流大仍会拉垮 5V 断电复位（软启动只缓解启动冲击）——需改独立供电

功率为估算值（无电流传感器），满载功率需按水泵铭牌标定

山洪曼宁 70% 缺超声波水位传感器，待补

尖峰检测阈值待实测标定

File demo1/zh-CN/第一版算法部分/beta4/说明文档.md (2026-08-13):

# Atmosphere Demo 1 说明文档（第四版 · Demo 1 最终版）

## 一、项目简介

Atmosphere 是面向野外溪流/漂流点的山洪 + 泥石流智能监测预警系统。

Demo 1 实现：土壤湿度、流速、风速三路环境采集 + 水泵 PWM 调速控制 + Web 实时监控 + 预警数学模型。

## 二、硬件连接方式

主控：Arduino Nano（ATmega328P，新 Bootloader）

土壤湿度传感器：AO→A2（模拟量），DO→D2（数字/断线检测），VCC→5V，GND→GND

流速传感器 YF-S401：红线→5V，黄线→D8（信号），黑线→GND

水泵：IO 接 D9（PWM 脚，软启动/调速，占空比越大抽水越快）；VCC/GND 接电源，D7 已拉低兜底

风速传感器（三杯式，0~5V）：接另一台电脑的 Arduino UNO A0，经 HTTP 转发到本机

## 三、软件实现

两个文件（均已放入本文件夹）：

FlowSensor.ino —— Arduino 固件：三路采集 + 水泵 PWM 调速（软启动），每秒输出一行 JSON 到串口（9600）

server.py —— Python Web 服务（端口 8080）：串口读取 + 风速 HTTP 集成 + 预警模型 + 网页（含水泵滑块调速 + 整机功率显示）

串口命令：发送速度值 0~255 + 换行（0 = 停止，255 = 全速）。

水泵调速：D9 PWM + 软启动（0→255 约 0.5 秒平滑升/降，抹平启动电流冲击）。

网页滑块：0~100% 拖动实时调速（150ms 防抖）；整机功率 = 固定功耗 0.4W + 占空比 × 水泵满载功率（默认 1.25W 估算，可标定）。

风速接口：对方电脑 http://192.168.1.200:8001/wind 返回 JSON（wind_ms / wind_kmh / temp / hum）。

## 四、预警模型

泥石流（已完整落地）：

危险指数 D = 0.40·S̄ + 0.30·Q̄ + 0.20·dQ̄ + 0.10·ΔS̄

S̄ 土壤湿度归一化，Q̄ 流量归一化，dQ̄ 流量突变，ΔS̄ 土壤湿度涨幅

门槛：土壤湿度 < 60%（土体未饱和）直接判安全，不参与 D 分级

特殊规则：土壤高湿 + 流量连涨 → 拉高等级

山洪（部分落地）：

曼宁公式 70%（缺超声波水位传感器，暂未落地）

尖峰检测 30%（用流量秒级变化率近似，滑动基准自适应，超当地 P95 判高风险）

滑动基准（自适应气候）：

24 小时滑动窗口，用 P10/P95 分位数判断「偏离当地正常多少」，数据积累 2 小时后生效。

预警档位（一级最严重）：

🟢 正常：D < 0.45（土壤湿度 < 60% 时直接安全）

🟡 三级预警：0.45 ≤ D < 0.55

🟠 二级预警：0.55 ≤ D < 0.75

🔴 一级预警：D ≥ 0.75

## 五、运行方式

编译上传 FlowSensor.ino 到 Arduino Nano

运行 python3 -u server.py

浏览器打开 http://localhost:8080 查看监控页面，拖滑块调节水泵速度

## 六、版本状态

**Demo 1 最终版**：beta4 为 Demo 1 的最终版本，后续开发转入 Demo 2（新增超声波水位传感器，补全山洪曼宁 70% 分量）。

## 七、已知问题

水泵从 Arduino 取电，高速时电流大仍会拉垮 5V 断电复位（软启动只缓解启动冲击）——需改独立供电

整机功率为估算值（无电流传感器），满载功率需按水泵铭牌标定

山洪曼宁 70% 缺超声波水位传感器，待补

尖峰滑动基准已落地，回退固定阈值（2.0 L/min/s）仍需实测标定

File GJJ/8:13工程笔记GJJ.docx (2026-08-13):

山谷阵雨测量预警方案—— 用 DHT11 + 三杯式风速传感器 + Arduino UNO，提前 10~30 分钟捕捉山谷暴雨

✦ 一、核心理念

山谷突发局部大雨，本质是对流性降水：来得快、局地性强、危害大，且大范围气象预报难以覆盖。本方案不“预报”天气，而是“感知雨前的物理前兆”——用百元级本地传感器捕捉雷暴“阵风锋”抵达时的地面信号，在暴雨到达前 10~30 分钟发出预警，为撤离河谷、收起帐篷、离开山脊争取宝贵时间。

✦ 二、科学依据

• 要测的雨：对流性降水（雷暴、阵雨、冰雹），雨前有典型地面信号，本方案可测

• 测不了的雨：系统性降水（梅雨锋、台风、冷锋），请依赖气象台与雷达

• 山谷为何易发暴雨：地形抬升触发对流、谷风热力效应、狭窄河谷汇流暴涨

• 阵风锋机制：雷暴下沉冷空气沿地面外推，先于主雨区 10~60 分钟到达——它就是大雨的“信使”

• 五大可测信号：阵风骤增、静风转突风、气温骤降、湿度突升、露点贴近气温

✦ 三、硬件清单（合计约 ¥80~130）

• Arduino UNO 主控（约 ¥25）：读取传感器、计算、报警

• DHT11 温湿度传感器（约 ¥5）：电容湿敏 + NTC 热敏，单总线协议，±2℃ / ±5%RH

• 三杯式风速传感器（约 ¥30~80）：风杯转动输出脉冲，风速 v = f × K

• 蜂鸣器 + 三色 LED + 面包板（约 ¥15）：三级报警与状态指示

• 供电与防护：移动电源 / 18650 电池、防辐射罩（纸杯 DIY，约 ¥0）

接线速记：D2←DHT11 · D3←风速脉冲（中断）· D8→蜂鸣器 · D9/10/11→LED

✦ 四、测量方法：多时间尺度消噪

• 1 秒级采样风速 → 3 秒阵风（短窗口抓尖峰）→ 分钟结算 → 30 分钟滚动基线

• DHT11 每 2 秒读取并判错（NaN）；温度取 5 分钟均值、湿度取 10 分钟均值

• 对比窗口：20 分钟温差（捕捉骤降）、60 分钟湿度差（捕捉突升）

• 用 Magnus 公式计算露点：气温-露点 ≤2℃ 且湿度 ≥70% 即接近饱和，比单看湿度更抗干扰

• 关键：传感器必须套防辐射罩，否则太阳直晒使温度虚高 5℃+，骤降信号失真

✦ 五、预警算法：多信号打分，三级预警（满分约 12 分）

• 阵风骤增 +3 · 静风后突风 +2 · 大风 +2

• 温度骤降 ≥3℃ +2，≥5℃ +3

• 湿度突升 +2 · 高湿突升 +3 · 湿度 ≥90% +1

• 露点贴近气温 +2

• ≥4 分一级戒备 → ≥6 分二级预警（10~30 分钟内撤离）→ ≥8 分三级强预警（立即离开）

• 判据持续 2 个结算周期防抖，报警后冷却 30 分钟防重复

✦ 六、程序设计要点

风速脉冲用中断计数（防漏脉冲）、volatile 修饰共享变量；环形缓冲 60 槽存储分钟数据；完整代码 weather_alarm.ino 可直接烧录，阈值参数集中定义，便于现场微调。

✦ 七、数据读取与标定

串口监视器 9600 波特率，每分钟输出一行：风速 / 阵风 / 温度 / 湿度 / 露点 / 得分 / 级别；可转存 CSV 或加 SD 卡记录。标定必做三件事：标定风速 K 值、DHT11 装防辐射罩、空跑 3~5 天采集当地基线。验收标准：真雨前 30 分钟至少触发二级预警，晴天误报不超过每天 1 次。

✦ 八、部署建议

布点选开阔处、离地 2~3 米，优先山脊、垭口、风口；避开溪边低洼与孤树最高点。20000mAh 移动电源可支撑约一周；长期运行用 18650 + 太阳能板 + TP4056 充电模块。Arduino 放入防水盒，线缆做滴水弯；DHT11 保持通风透气；每月检查风杯、传感器与电池。

✦ 九、局限与升级路线

当前方案只对对流性降水有效，提前量 10~30 分钟而非小时级；单点风速需温湿度交叉验证。升级路径（按性价比）：BMP280 气压计 → 风向标 → 翻斗雨量计 → DHT22/HTU21D → 土壤湿度与水位。终极形态：本地传感器负责分钟级临近预警，雷达与短临预报负责小时级，土壤湿度与水位负责成灾预警——三段时间尺度拼成完整的山野防雨体系。

✦ 十、行动清单

1. 采购硬件（Arduino UNO / DHT11 / 三杯风速 / 蜂鸣器 / LED）

2. 面包板接线 → 烧录 weather_alarm.ino → 串口确认每分钟数据

3. 标定风速 K 值，给 DHT11 加防辐射罩

4. 部署到山谷测点，连续记录 3~5 天建立基线

5. 复盘每次降雨，微调阈值，做到“真雨必报、晴天少报”

6. （进阶）加装气压计与风向标，联调雷达 App，形成完整防雨体系

我做啥了：

3D 打印改良 + GitHub 入门

今天围绕两件事推进：一是把项目 3D 打印的外壳彻底测量并改良了设计，二是学会了用 GitHub 管理项目文件。

✦ 一、3D 打印改良（Terrific Trug 外壳）

• 精确测量模型：外壳 高154.0 / 宽123.6 / 长178.4 mm；内腔 高146 / 宽69.5 / 长132 mm，壁厚 10~12mm

• 整理出全部配件尺寸表：显示屏、Arduino、风杯、温湿度、土壤湿度、水流传感器、面包板

• 验证装配方案：风杯外置，其余六件全部装进内腔；100% 能装但偏挤，放大到 120% 最舒服

• 确定打印尺寸区间：最小 93%，推荐 120%（高184.8 / 宽148.3 / 长214.1），最大 143.5%（Bambu P1S 打印体积 256mm 的上限）

• 设计分层结构：模型切成三层——底座 0~30mm、中层 30~90mm、上层 90~154mm，每层对应一组配件，安装像搭积木一样逐层放入，方便很多

• 用 Tinkercad 导出 120% 和 104.3% 两个版本，确认 PLA 可打、开口朝上无需支撑

✦ 二、GitHub 入门

• 学会用 GitHub CLI（gh）登录并完成浏览器授权

• 把项目文件推上仓库 liangaustin/Atmosphere：STL 模型（Sizzling Jaban 系列、Terrific Trug 全版本、LouisGJJ）、pro intro 文档、测量基准文档

• 看懂仓库的文件夹分工（GJJ/、AustinLiang/、wanglihui/），把自己的文件归到 GJJ/

• 学会推送被拒的处理：先 git pull --rebase 合并远端新提交，再重新 push，不再怕冲突

• 养成上传前先校验的习惯：量尺寸、查三角形数、用哈希查重，避免重复传文件

✦ 今日收获

从"量尺寸、算空间"到"分层设计、导出模型"，再到"推上 GitHub 和队友共享"——3D 打印这件事今天走完了一个完整闭环：设计 → 测量 → 验证 → 分层 → 上传。以后改模型、传文件都心里有数了。

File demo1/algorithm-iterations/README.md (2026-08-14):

# 算法迭代 / Algorithm Iterations

预警算法迭代归档目录，每代算法一份技术文档（含优势 / 缺陷 / 特点），随迭代持续更新。
Archive of warning-algorithm iterations. Each algorithm version has one technical document (strengths / limitations / characteristics), updated as iterations continue.

## 文档索引 / Documents

| 算法版本 / Version | 中文 / Chinese | English |
| --- | --- | --- |
| v1（第一版 / v1） | [数学预警模型第一版技术文档](./zh-CN/数学预警模型第一版技术文档.md) | [Mathematical Warning Model v1](./en-US/Mathematical-Warning-Model-v1-Technical-Documentation.md) |
| v2（第二版 / v2） | [数学预警模型第二版技术文档](./zh-CN/数学预警模型第二版技术文档.md) | [Mathematical Warning Model v2](./en-US/Mathematical-Warning-Model-v2-Technical-Documentation.md) |

## 说明 / Notes

- 目前已有 v1/v2 两代算法文档，完整内容随迭代持续补充
- 后续版本（v3 等）文档将在此目录继续归档
- v1/v2 archived; future versions (v3, ...) will be added here.

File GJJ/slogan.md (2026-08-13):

Short & Punchy

Come to life naturally.

Go wild. Be free.

Nature is calling.

Live outside the lines.

Return to the real.

Born to be wild.

Naturally yours.

Wild at heart.

Poetic & Evocative

Where the earth holds you close.

Let the wild remind you who you are.

Breathe in the world, breathe out yourself.

Lose yourself in nature’s arms.

Find your quiet in the loud of the wild.

The forest remembers your name.

Wander where the Wi-Fi is weak and the soul is strong.

Active & Inviting

Step into the green.

Walk on the wild side.

Leave the road, take the trail.

Unplug to reconnect.

Escape the noise. Find the silence.

Leave footprints, not carbon.

Hike more, worry less.

Spiritual & Mindful

Reconnect with the rhythm of the earth.

Ground yourself.

Nature heals, if you let it in.

Come home to yourself, in nature.

Find your center among the trees.

Let the earth be your therapist.

Playful & Modern

Hug a tree, it’s good for you.

Nature: better than your screen.

Let’s get lost where Google can’t find us.

Fresh air, no download required.

Mother Nature called. She wants you back.

Focus on the Senses

Feel the breeze. Hear the silence. See the life.

Touch the wild.

Smell the earth, taste the freedom.

Taglines That Flip “Embrace” Imaginatively

Wrap the world in your arms.

Held by the horizon.

Fall into the open sky.

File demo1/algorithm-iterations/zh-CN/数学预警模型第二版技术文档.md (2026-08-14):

# 数学预警模型 · 第二版技术文档

**版本：** v2（第二版）
**算法名称：** 传感器标定对齐 + 快速滑动基准预警模型
**日期：** 2026-08-14

---

## 一、v2 相对 v1 的改动

| 项目 | v1 | v2 | 原因 |
|---|----|----|----|
| 预警等级命名 | 1=三级 / 3=一级（一级最严重） | **0=正常 / 1=一级 / 2=二级 / 3=三级（三级最严重）** | 等级体系规范：数字越大越严重，最高为三级 |
| 泥石流权重 | 0.40S+0.30Q+0.20dQ+0.10ΔS | **0.30S+0.35Q+0.20dQ+0.15ΔS** | 土壤易饱和顶分，降权重；流量（山洪信号）升最高权重 |
| Q_MAX（满槽流量） | 30 L/min | **3 L/min** | 对齐 YF-S401 实测量程（实测最大 ~1.7） |
| DQ_MAX（变化率上限） | 5 L/min/s | **0.5 L/min/s** | 实测秒级跳变 ~0.3 |
| 尖峰回退阈值 | 2.0 | **0.5** | 同上，让流量数据真正参与推理 |
| 滑动基准冷启动 | 2 小时 | **15 分钟** | 更快自适应当地气候 |
| 山洪独立路径 F | 0.6Q̄+0.4dQ̄ | 保留 | 流量暴涨独立触发，不受土壤门槛限制 |
| LCD 显示 | 无 | **风速/土湿度/水流速/预警等级** | 现场直观显示 |
| 流速脉冲诊断 | 单沿计数 | **上升/下降沿分开计数 + D8 电平** | 快速定位接线/沿方向问题 |

---

## 二、算法结构（v2）

```
最终等级 = max(泥石流 D, 山洪 F, 风速, 流量尖峰, 突变, 土壤饱和)   ← 0~3
```

**等级定义（数字越大越严重）：**

| 等级 | 含义 | 触发示例 |
|---|---|---|
| 0 | 正常 | 各因子均低于阈值 |
| 1 | 一级预警（最轻） | D/F ≥ 0.45，或风速 ≥25 km/h，或突变 |
| 2 | 二级预警 | D/F ≥ 0.55，或风速 ≥40 km/h，或尖峰 ≥P95 |
| 3 | 三级预警（最严重） | D/F ≥ 0.75，或风速 ≥60 km/h |

### 1. 泥石流路径

```
D = 0.30 × S̄ + 0.35 × Q̄ + 0.20 × dQ̄ + 0.15 × ΔS̄
```

- 土壤 <60%（未饱和）时跳过本路径（山洪/风速不受限）
- 特殊规则：土壤超当地 P90 + 流量上涨 + 5 分钟持续上升 → 直接三级；土壤超当地 P90 + 流量 ≥70% 满槽 → 二级；土壤 10 分钟涨幅 ≥20% → 至少一级

### 2. 山洪路径（独立指数）

```
F = 0.60 × Q̄ + 0.40 × dQ̄
```

- 不受土壤门槛限制，流量暴涨即触发
- 曼宁公式 70% 分量的流量近似替代（本方案不采用超声波水位传感器——水位与流速功能重叠，流速为核心）

### 3. 风速路径

≥25 km/h → 一级；≥40 km/h → 二级；≥60 km/h → 三级

### 4. 流量尖峰路径

秒级变化率超当地历史 P95 → 二级；≥0.8 归一化 → 一级

### 5. 突变路径（秒级响应）

土壤 5 秒内涨 ≥20% / 风速 60 秒内涨 ≥12 km/h → 立即一级

### 6. 土壤饱和路径（v2 新增）

土壤 ≥85% 或超当地 P90 → **至少一级**（土体饱和本身就是危险，不依赖流量；持续生效，直到土壤回落）

### 7. 滞回保持（v2 新增，防抖）

- 升级：立即生效并保持
- 降级：需超过保持时间才生效 —— 一级 10 秒 / 二级 15 秒 / 三级 20 秒
- 防止单点抖动/瞬时回落造成的等级闪烁

---

## 三、滑动基准（v2 调整）

- 窗口 24h 每分钟采样，把当前值映射到当地 [P10,P95] 区间 → 0~1
- **冷启动缩短至 15 分钟**：数据攒 15 分钟即启用，之前的 2 小时等待期砍掉
- 数据不足时回退绝对值：Qn=flow/3、dQn=变化率/0.5（对齐传感器量程）

---

## 四、LCD 显示（v2 新增）

- 硬件：I2C LCD 1602（SCL→A5，SDA→A4，地址 0x27）
- 显示内容（ASCII，每秒刷新）：

```
W12.3 S45% F0.50     ← 风速 km/h · 土湿度 % · 水流速 L/min
ALARM:3 L3           ← 预警等级 0~3（0=正常，3=三级最严重）
```

- 风速与预警等级由服务端（server.py）通过串口下发（`D<风速>,<等级>` 协议），土壤与流速由 Arduino 本地读取

---

## 五、优势

1. **流量数据真正参与推理**：标定参数对齐传感器量程后，Q̄/dQ̄ 从"压扁的蚊子腿"变成有效因子，山洪路径响应真实水流变化
2. **滑动基准快速启用**：15 分钟冷启动，插电一刻钟后自适应当地气候
3. **等级体系规范**：0~3 数字越大越严重，LCD/网页/文档口径统一（三级=最高）
4. **现场可视化**：LCD 实时显示四路核心数据，不依赖电脑/网页即可观测
5. **诊断能力**：脉冲双向沿计数 + 电平输出，接线/信号问题 30 秒定位
6. 保留 v1 全部优点：多路径独立、简单可解释、冷启动可用

---

## 六、缺陷

1. **流量计量程仍窄**：YF-S401 实测 0.05~3 L/min，真实洪水流量远超量程——标定参数是为当前测试环境（水泵+管道）服务的，换环境需重新标定
2. **风速数据依赖外部电脑**（192.168.1.200:8001），该服务离线时风速路径失效（LCD 风速显示 0）
3. **滑动基准 15 分钟**仍可能不够稳：突发天气下前 15 分钟基准质量差，回退绝对值精度有限
4. **突变阈值仍是经验值**（土壤 5s+20%、风速 60s+12km/h），未做统计标定
5. **LCD 仅 ASCII**：无法显示中文，现场人员需熟悉 0~3 数字含义
6. **等级硬阈值**：0.45/0.55/0.75 阶梯跳变，无置信度/持续性判定（单点抖动可能误触发）

---

## 七、特点

1. 实时性：每秒重算 + LCD 每秒刷新 + 网页 0.5 秒刷新
2. 双端显示：网页（完整指标）+ LCD（现场核心指标）
3. 参数可标定：Q_MAX/DQ_MAX/尖峰阈值来自实测，非拍脑袋
4. 模块化：5 条路径独立，后续可单独迭代

---

## 八、版本规划

- **v2.x 候选**：突变阈值按历史分布标定（替代经验值）；~~预警加持续性判定（连续 N 秒超阈值才触发，防抖）~~ —— 已实现：滞回保持（一级 10s / 二级 15s / 三级 20s）
- **v3 候选**：风速接入本机（传感器迁移到综合板，摆脱外部电脑依赖）；LCD 显示山洪 F/泥石流 D 数值

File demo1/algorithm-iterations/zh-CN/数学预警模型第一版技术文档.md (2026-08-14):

# 数学预警模型 · 第一版技术文档

**版本：** v1（第一版）
**算法名称：** 风速基准线 + 滑动基准预警模型
**日期：** 2026-08-14

---

## 一、算法总览

本版算法由 5 条独立预警路径组成，每秒计算一次，最终等级取各路径**最高值**：

```
最终等级 = max(泥石流 D, 山洪 F, 风速, 流量尖峰, 突变)
```

等级定义：0 = 正常 / 1 = 三级预警 / 2 = 二级预警 / 3 = 一级预警（一级最严重）

---

## 二、五条预警路径

### 1. 泥石流路径（四因子加权）

```
D = 0.30 × S̄ + 0.35 × Q̄ + 0.20 × dQ̄ + 0.15 × ΔS̄
```

> v1 权重调整说明：土壤湿度 0.40 → 0.30（土湿易饱和顶分，降低主导性）；流量升为最高权重 0.35（山洪信号更关键）；ΔS̄ 0.10 → 0.15。

| 因子 | 含义 | 归一化方式 |
|---|---|---|
| S̄ | 土壤湿度水平 | 滑动基准 [P10,P95] 归一化，数据不足回退 实测值/100 |
| Q̄ | 流量水平 | 滑动基准归一化，数据不足回退 流量/30 L/min |
| dQ̄ | 流量变化率 | min(变化率/5 L/min/s, 1) |
| ΔS̄ | 土壤 10 分钟涨幅 | min(涨幅/15%, 1) |

**触发门槛：** 土壤湿度 < 60%（土体未饱和）时泥石流路径直接跳过——土不饱和泥石流起不来。

**分级阈值：** D ≥ 0.45 三级 / ≥ 0.55 二级 / ≥ 0.75 一级

**特殊规则（优先）：**
- 土壤高于当地 P90 + 流量上升 + 连续 5 分钟上涨 → 直接一级
- 土壤高于当地 P90 + 流量 ≥ 满槽 70% → 直接二级
- 土壤 10 分钟涨幅 ≥ 20% → 至少三级

### 2. 山洪路径（独立指数，本版新增重点）

```
F = 0.60 × Q̄ + 0.40 × dQ̄
```

- **不受土壤门槛限制**——只要流量暴涨就触发，模拟上游暴雨型山洪（土壤还没饱和洪水已经来了）
- 分级阈值与泥石流相同：F ≥ 0.45 三级 / ≥ 0.55 二级 / ≥ 0.75 一级
- 本质是曼宁公式的流量近似替代（缺超声波水位传感器，用流量水平+变化率顶 70% 分量）

### 3. 风速路径

| 风速 | 等级 |
|---|---|
| ≥ 25 km/h | 三级 |
| ≥ 40 km/h | 二级 |
| ≥ 60 km/h | 一级 |

- 风速风险度：`wind_risk = min(风速/40, 1)`，用于展示
- 强风视为强对流天气前兆（山洪诱因）

### 4. 流量尖峰路径

- 每秒流量变化率与当地 24h 历史分布对比，超 P95 视为高风险
- spike_risk ≥ 0.8 → 三级；≥ 1.0（超 P95）→ 二级
- 基准数据不足时回退绝对值：变化率 ≥ 2 L/min/s 为满格

### 5. 突变路径（秒级响应）

| 突变 | 触发 |
|---|---|
| 土壤 5 秒内涨 ≥ 20% | 立即三级（饱和渗流信号） |
| 风速 60 秒内涨 ≥ 12 km/h | 立即三级（狂风骤起） |

---

## 三、滑动基准（本版核心机制）

- **窗口：** 24 小时，每分钟采样 1 点
- **归一化：** 把当前值映射到该地点历史 [P10, P95] 区间的 0~1 相对位置
- **作用：** 自适应当地气候——干旱地区 20% 湿度算高，湿润地区 60% 才算高；不用人工标定阈值
- **冷启动：** 数据不足 2 小时时滑动基准不启用，回退绝对值阈值（土壤/100、流量/30）

---

## 四、优势

1. **自适应强**：滑动基准让同一套算法在不同气候区（干旱/湿润/沿海）都能用，不用重新标定
2. **多路径互不干扰**：泥石流/山洪/风速/尖峰/突变 5 条路独立，一条失灵不影响其他；土壤门槛卡不住山洪
3. **突变秒级响应**：突发场景（土壤骤湿、狂风骤起、流量暴涨）不用等 5-10 分钟窗口
4. **简单直观**：无神经网络/复杂统计，全部是加权+阈值，好部署、好调试、好解释（对现场人员友好）
5. **冷启动可用**：基准数据不足时自动回退绝对值，插上就能跑

---

## 五、缺陷

1. **山洪曼宁 70% 分量缺失**：缺超声波水位传感器，用水位算曼宁公式（R=0.7M+0.3S）的主干做不了，只能用流量近似，精度打折
2. **风速阈值固定**：25/40/60 km/h 是经验值，没按当地风气候做滑动基准（海边和内陆的风"大"定义不同）
3. **土壤 <60% 硬门槛可能漏报**：土不饱和但上游暴雨型山洪仍可能发生——已用山洪 F 路径兜底，但 F 依赖流量传感器，若流量计失准则漏报
4. **冷启动窗口期**：前 2 小时用绝对值回退，对"异常地区"（特别干旱/湿润）可能误判
5. **流量传感器量程窄**：YF-S401 只能测 0.3-3 L/min，小水流/大水流量都测不准，影响 Q̄ 和 dQ̄ 质量
6. **土壤 10 分钟涨幅滞后**：ΔS̄ 因子要 10 分钟窗口才有值，骤湿场景靠突变路径兜底（5 秒 +20%），两者衔接处有盲区
7. **分级是硬阈值**：0.45/0.55/0.75 阶梯跳变，没有概率/置信度输出，边界值（0.44 vs 0.45）语义跳跃

---

## 六、特点

1. **实时性**：每秒重算一次，网页 0.5 秒刷新，数据落地即预警
2. **可视化**：网页预警卡实时显示泥石流 D、山洪 F、土湿 S̄、流量 Q̄、突变 dQ̄、土湿涨 ΔS̄、尖峰风险、风速风险 8 项指标
3. **多传感器融合**：土壤湿度 + 水流速 + 风速 + 温湿度（DHT11）四路数据进模型
4. **可解释**：每个等级都能追溯到具体哪条路径、哪个因子超阈值，适合答辩/验收时讲清楚
5. **模块化**：5 条路径互相独立，后续版本可以单独替换其中任何一条（比如补上曼宁 70% 分量）而不影响其他

---

## 七、版本规划（迭代方向）

- **v2 预期**：接入超声波水位传感器 → 补全曼宁公式 70% 分量（R = 0.7M + 0.3S）
- **v2 预期**：风速也做滑动基准自适应（替代固定 25/40/60 阈值）
- **v2 预期**：预警加置信度/持续性判定（连续 N 秒超阈值才触发，减少单点误报）

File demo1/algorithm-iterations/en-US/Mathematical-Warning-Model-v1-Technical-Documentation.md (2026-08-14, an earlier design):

# Mathematical Warning Model · v1 Technical Documentation

**Version:** v1 (first release)
**Algorithm name:** Wind baseline + sliding baseline warning model
**Date:** 2026-08-14

---

## 1. Overview

The v1 model consists of **5 independent warning paths**, computed every second. The final level is the **maximum** of all paths:

```
Final level = max(Debris flow D, Flash flood F, Wind, Flow spike, Surge)
```

Levels: 0 = Normal / 1 = Level-3 warning / 2 = Level-2 warning / 3 = Level-1 warning (most severe)

---

## 2. Warning Paths

### 2.1 Debris Flow (four-factor weighted)

```
D = 0.30 × S̄ + 0.35 × Q̄ + 0.20 × dQ̄ + 0.15 × ΔS̄
```

| Factor | Meaning | Normalization |
|---|---|---|
| S̄ | Soil moisture level | Sliding baseline [P10,P95] percentile; fallback: reading/100 |
| Q̄ | Flow level | Sliding baseline; fallback: flow/30 L/min |
| dQ̄ | Flow change rate | min(rate/5 L/min/s, 1) |
| ΔS̄ | Soil 10-min rise | min(rise/15%, 1) |

**Gate:** soil moisture < 60% (unsaturated) → debris flow path skipped (debris flow cannot start in dry soil).

**Thresholds:** D ≥ 0.45 → L3 / ≥ 0.55 → L2 / ≥ 0.75 → L1

**Special rules (priority):**
- Soil above local P90 + rising flow + 5-min continuous rise → L1 directly
- Soil above local P90 + flow ≥ 70% of channel capacity → L2 directly
- Soil 10-min rise ≥ 20% → at least L3

> v1 weight adjustment note: soil moisture 0.40 → 0.30 (soil saturates easily and dominated the score); flow raised to the highest weight 0.35 (flash-flood signal is more critical); ΔS̄ 0.10 → 0.15.

### 2.2 Flash Flood (independent index, new in this version)

```
F = 0.60 × Q̄ + 0.40 × dQ̄
```

- **Not gated by soil moisture** — triggers on flow surge alone, simulating upstream rainstorm floods (water arrives before soil saturates)
- Same thresholds: F ≥ 0.45 → L3 / ≥ 0.55 → L2 / ≥ 0.75 → L1
- Acts as a flow-based approximation of the Manning equation (ultrasonic water-level sensor not yet available, so flow level + change rate substitute for the 70% Manning component)

### 2.3 Wind

| Wind speed | Level |
|---|---|
| ≥ 25 km/h | L3 |
| ≥ 40 km/h | L2 |
| ≥ 60 km/h | L1 |

- Wind risk index: `wind_risk = min(wind/40, 1)` (for display)
- Strong wind treated as a precursor of severe convection (flash-flood trigger)

### 2.4 Flow Spike

- Per-second flow change rate compared against the local 24h historical distribution; above P95 = high risk
- spike_risk ≥ 0.8 → L3; ≥ 1.0 (above P95) → L2
- Fallback when baseline insufficient: rate ≥ 2 L/min/s = full scale

### 2.5 Surge (second-level response)

| Surge | Trigger |
|---|---|
| Soil rises ≥ 20% within 5 s | L3 immediately (saturation/seepage signal) |
| Wind rises ≥ 12 km/h within 60 s | L3 immediately (sudden gale) |

---

## 3. Sliding Baseline (core mechanism)

- **Window:** 24 h, sampled once per minute
- **Normalization:** map current value to the [P10, P95] range of local history → 0~1 relative position
- **Purpose:** self-adapts to local climate — 20% moisture can be "high" in arid regions, 60% only "high" in humid regions; no manual threshold calibration
- **Cold start:** baseline inactive until 2 h of data; falls back to absolute thresholds (soil/100, flow/30)

---

## 4. Strengths

1. **Adaptive:** sliding baseline makes one algorithm work across climates without recalibration
2. **Independent paths:** debris flow / flash flood / wind / spike / surge do not interfere; a failed path does not block others; soil gate cannot block the flood path
3. **Second-level surge response:** sudden events (soil saturation, gale, flow surge) do not wait for 5–10 min windows
4. **Simple & explainable:** no neural networks or complex statistics — weighted sums + thresholds, easy to deploy, debug, and explain to field staff
5. **Cold-start capable:** falls back to absolute thresholds when baseline data is insufficient

---

## 5. Limitations

1. **Missing 70% Manning component:** no ultrasonic water-level sensor, so the main Manning equation (R = 0.7M + 0.3S) cannot run; flow approximation reduces accuracy
2. **Fixed wind thresholds:** 25/40/60 km/h are empirical; not adapted to local wind climate (coastal vs inland "strong wind" differ)
3. **Soil <60% hard gate may miss events:** upstream rainstorm floods can occur while local soil is still dry — mitigated by the flood F path, but F depends on the flow sensor; a failed flow sensor means missed alerts
4. **Cold-start window:** first 2 h uses absolute fallbacks, which may misjudge extreme climates (very arid/humid)
5. **Narrow flow-sensor range:** YF-S401 measures 0.3–3 L/min only; very low/high flows are inaccurate, degrading Q̄ and dQ̄
6. **10-min soil-rise lag:** ΔS̄ needs a 10-min window; sudden wetting relies on the surge path (5 s +20%), leaving a gap in between
7. **Hard thresholds:** 0.45/0.55/0.75 step jumps with no probability/confidence output; boundary values (0.44 vs 0.45) jump semantically

---

## 6. Characteristics

1. **Real-time:** recomputed every second; web page refreshes every 0.5 s
2. **Visualized:** warning card shows 8 metrics — debris D, flood F, soil S̄, flow Q̄, dQ̄, ΔS̄, spike risk, wind risk
3. **Multi-sensor fusion:** soil moisture + water flow + wind + temperature/humidity (DHT11)
4. **Explainable:** every level can be traced to a specific path and factor, suitable for review/demo presentations
5. **Modular:** 5 independent paths; any path can be replaced separately in future versions (e.g., add the Manning 70% component) without affecting the others

---

## 7. Version Plan (iteration direction)

- **v2 (planned):** add ultrasonic water-level sensor → complete the Manning 70% component (R = 0.7M + 0.3S)
- **v2 (planned):** sliding-baseline adaptation for wind thresholds (replace fixed 25/40/60)
- **v2 (planned):** confidence/persistence check (trigger only after N seconds above threshold to reduce single-point false alarms)

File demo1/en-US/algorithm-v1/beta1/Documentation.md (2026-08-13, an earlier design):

# Atmosphere Demo 1 Documentation (First Edition)

# 1. Project Overview

Atmosphere is a smart monitoring and early-warning system for flash floods and debris flows at outdoor streams / drifting sites.

Demo 1 implements: soil moisture, flow, and wind sensing + pump control + web monitoring + early-warning model.

# 2. Hardware Connections

Main controller: Arduino Nano (ATmega328P, new bootloader)

Soil moisture sensor: AO->A2 (analog), DO->D2 (digital / disconnection detect), VCC->5V, GND->GND

Flow sensor YF-S401: Red->5V, Yellow->D8 (signal), Black->GND

Pump: D7 (HIGH = pump on, LOW = pump off)

Wind sensor (3-cup, 0~5V): on another computer's Arduino UNO A0, forwarded to this machine via HTTP

# 3. Software Implementation

Two files (both included in this folder):

FlowSensor.ino — Arduino firmware: three-channel sensing + pump control, outputs one JSON line per second over serial (9600)

server.py — Python web service (port 8080): serial reading + wind HTTP integration + warning model + web page

Serial command (single byte): send 1 to turn pump on / 0 to turn off.

Wind endpoint: remote computer http://192.168.1.200:8001/wind returns JSON (wind_ms / wind_kmh / temp / hum).

# 4. Warning Model

Debris flow (fully implemented):

Danger index D = 0.40·S̄ + 0.30·Q̄ + 0.20·dQ̄ + 0.10·ΔS̄

S̄ normalized soil moisture, Q̄ normalized flow, dQ̄ flow spike, ΔS̄ soil-moisture rise

Special rules: high soil moisture + sustained flow rise -> escalate level

Flash flood (partially implemented):

Manning formula 70% (needs ultrasonic water-level sensor, not yet implemented)

Spike detection 30% (approximated by per-second flow change rate, threshold TBD)

Sliding baseline (climate-adaptive):

A 24-hour sliding window uses P10/P95 percentiles to judge "how far above local normal"; activates after 2 hours of data.

Warning levels (Level 1 = most severe):

🟢 Normal: D < 0.30

🟡 Level 3 Alert: 0.30 ≤ D < 0.55

🟠 Level 2 Alert: 0.55 ≤ D < 0.75

🔴 Level 1 Alert: D ≥ 0.75

# 5. How to Run

Compile and upload FlowSensor.ino to the Arduino Nano

Run: python3 -u server.py

Open http://localhost:8080 in a browser

# 6. Known Issues

Pump powered from the Arduino causes unstable supply and repeated USB resets (auto on/off) — needs an independent power supply

Flash-flood Manning 70% missing ultrasonic water-level sensor, pending

Spike detection threshold needs field calibration

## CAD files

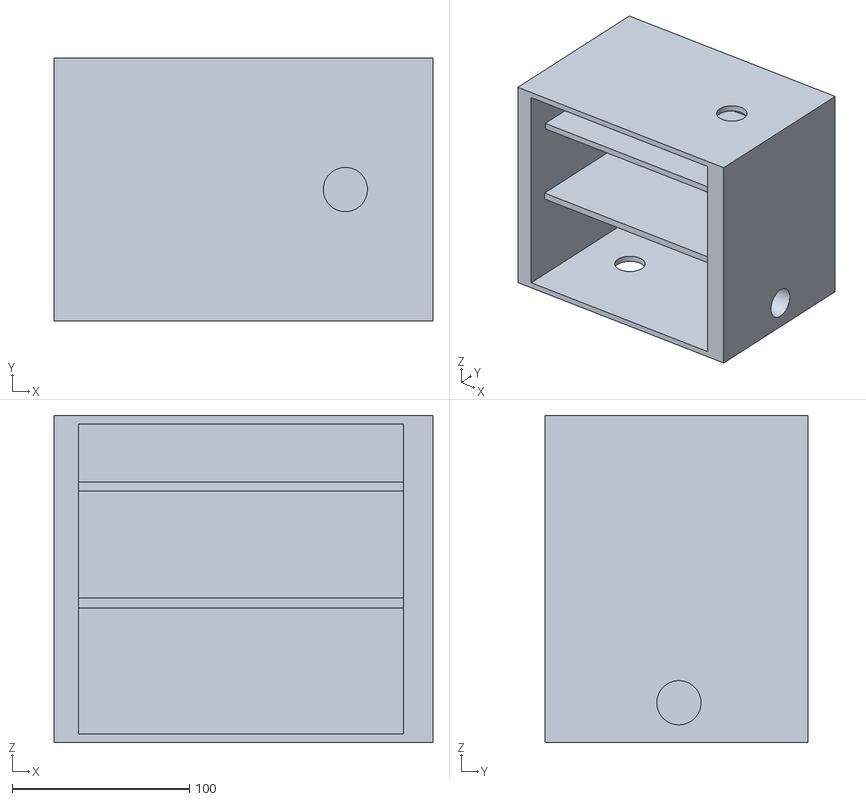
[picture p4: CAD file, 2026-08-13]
GJJ/LouisGJJ.stl
214.1 x 148.3 x 184.8

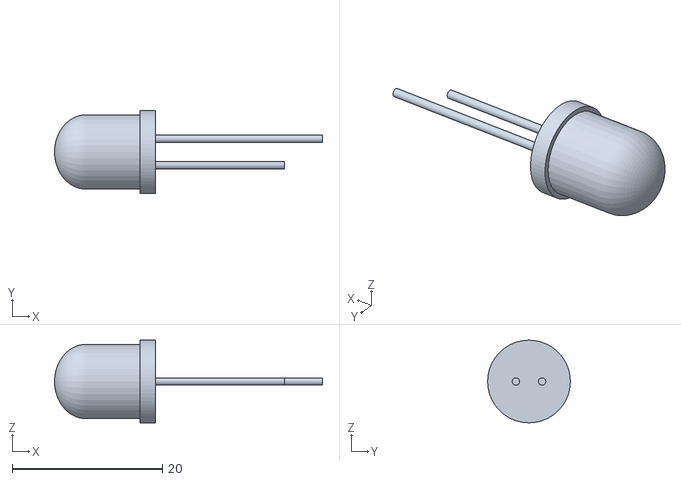
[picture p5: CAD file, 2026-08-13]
GJJ/Sizzling Jaban.stl
35.6 x 11.0 x 11.0

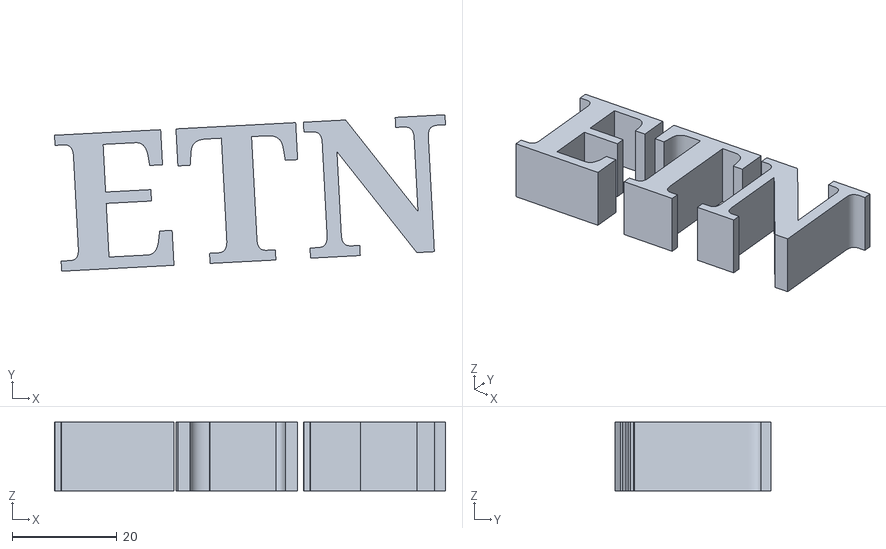
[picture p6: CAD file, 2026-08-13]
GJJ/Terrific Trug (small).stl
74.7 x 29.9 x 13.1

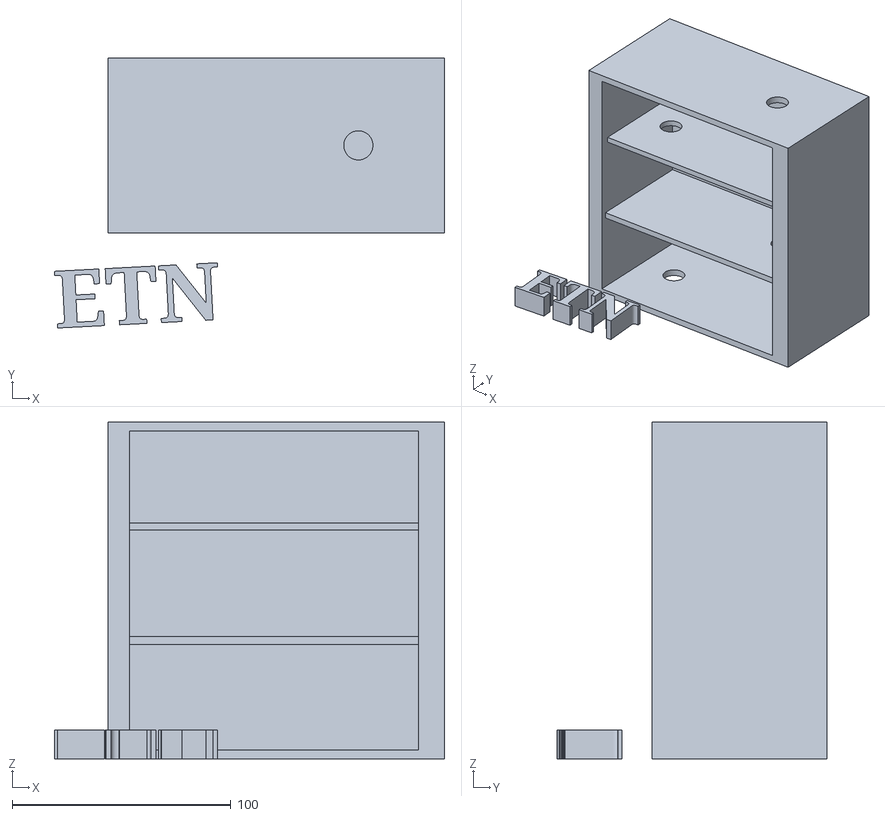
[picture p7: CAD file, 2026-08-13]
GJJ/Terrific Trug.stl
178.4 x 123.6 x 154.0

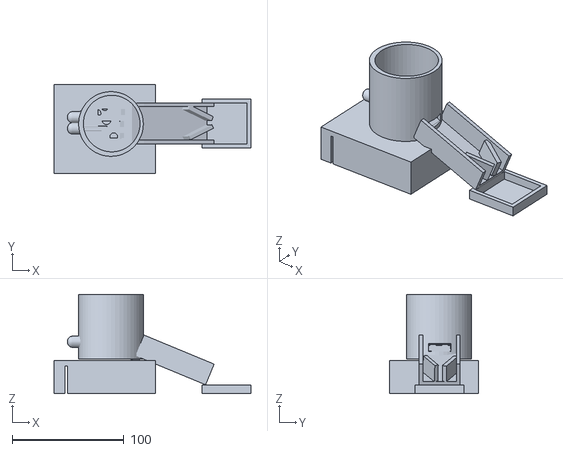
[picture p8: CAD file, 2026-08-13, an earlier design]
GJJ/Sizzling Jaban (1).stl
176.4 x 80.0 x 89.0

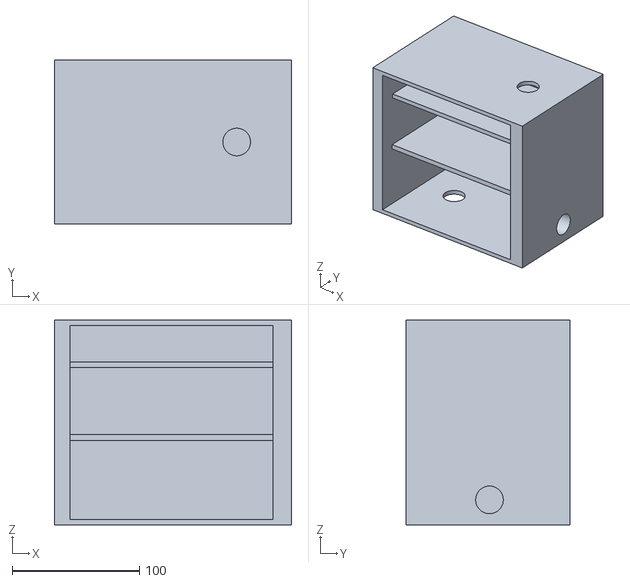
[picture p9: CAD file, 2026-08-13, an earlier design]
GJJ/Terrific Trug (3).stl
186.1 x 128.9 x 160.6

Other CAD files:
GJJ/Sizzling Jaban (2).stl

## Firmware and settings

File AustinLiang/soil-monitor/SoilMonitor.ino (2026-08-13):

/*
 * Atmosphere - 土壤湿度传感器测试（带断线检测）
 * AO → A0，DO → D2，VCC → 5V，GND → GND
 */

const int AO_PIN = A0;
const int DO_PIN = 2;

void setup() {
  Serial.begin(9600);
  pinMode(DO_PIN, INPUT_PULLUP);  // 启用内部上拉，拔掉时稳定为 HIGH
}

void loop() {
  int raw = analogRead(AO_PIN);

  // 断线检测：读5次，看波动
  int minV = raw, maxV = raw;
  for (int i = 0; i < 4; i++) {
    delay(10);
    int v = analogRead(AO_PIN);
    if (v < minV) minV = v;
    if (v > maxV) maxV = v;
  }
  int jitter = maxV - minV;

  // 悬空引脚噪声大且值接近1023（上拉），或波动超过200判为断线
  bool disconnected = (jitter > 200) || (raw > 1010);

  int percent = disconnected ? -1 : constrain(map(raw, 0, 1023, 100, 0), 0, 100);
  bool dry = digitalRead(DO_PIN);

  Serial.print("{\"raw\":");
  Serial.print(raw);
  Serial.print(",\"percent\":");
  Serial.print(percent);
  Serial.print(",\"dry\":");
  Serial.print(dry ? "true" : "false");
  Serial.print(",\"jitter\":");
  Serial.print(jitter);
  Serial.print(",\"connected\":");
  Serial.print(disconnected ? "false" : "true");
  Serial.println("}");

  delay(500);
}

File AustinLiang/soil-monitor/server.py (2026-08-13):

#!/usr/bin/env python3
"""土壤湿度 Web 监控"""
import json, time, http.server, threading, sys
import serial

SERIAL_PORT = "/dev/cu.usbserial-14120"
WEB_PORT = 8080
latest = {"raw": 0, "percent": -1, "dry": True, "connected": False, "jitter": 0, "time": ""}

def read_serial():
    global latest
    try:
        ser = serial.Serial(SERIAL_PORT, 9600, timeout=1)
        time.sleep(1)
        print(f"✅ 串口已连接: {SERIAL_PORT}")
        while True:
            line = ser.readline().decode(errors='ignore').strip()
            try:
                data = json.loads(line)
                data["time"] = time.strftime("%H:%M:%S")
                latest = data
            except json.JSONDecodeError:
                pass
    except Exception as e:
        print(f"❌ 串口错误: {e}")
        sys.exit(1)

HTML = """<!DOCTYPE html>
<html lang="zh-CN">
<head>
<meta charset="UTF-8">
<meta name="viewport" content="width=device-width, initial-scale=1.0">
<title>Atmosphere — 土壤湿度</title>
<style>
*{margin:0;padding:0;box-sizing:border-box}
body{font-family:-apple-system,system-ui,sans-serif;background:#0f1923;color:#e0e0e0;
  min-height:100vh;display:flex;flex-direction:column;align-items:center;justify-content:center;padding:20px}
h1{font-size:1.8em;color:#4fc3f7;margin-bottom:5px}
.sub{color:#78909c;margin-bottom:25px;font-size:.9em}
.card{background:#1a2a36;border-radius:16px;padding:30px 40px;max-width:480px;width:100%;text-align:center}
.gauge{position:relative;width:200px;height:200px;margin:0 auto 20px}
.gauge svg{transform:rotate(-90deg)}
.gauge .bg{fill:none;stroke:#1e3a4a;stroke-width:10}
.gauge .fill{fill:none;stroke-width:10;stroke-linecap:round;transition:all .5s ease}
.gauge .val{position:absolute;top:50%;left:50%;transform:translate(-50%,-50%);font-size:2.6em;font-weight:700}
.gauge .unit{font-size:.35em;color:#78909c}
.status{font-size:1.1em;padding:6px 18px;border-radius:20px;display:inline-block;margin:10px 0}
.status.wet{background:#1b5e20;color:#81c784}
.status.dry{background:#b71c1c;color:#ef9a9a}
.status.off{background:#37474f;color:#90a4ae}
.row{display:flex;gap:10px;margin-top:15px}
.col{flex:1;background:#1e3a4a;border-radius:10px;padding:12px}
.col .lb{font-size:.7em;color:#78909c}
.col .vl{font-size:1.1em;font-weight:600;margin-top:4px}
.time{color:#546e7a;font-size:.75em;margin-top:15px}
.warn{background:#3e2723;color:#ffab91;padding:8px 15px;border-radius:8px;display:inline-block;margin:10px 0;font-size:.9em}
</style>
</head>
<body>
<h1>🌱 Atmosphere</h1>
<div class="sub">土壤湿度实时监测</div>
<div class="card" id="card">
  <div class="gauge">
    <svg width="200" height="200" viewBox="0 0 200 200">
      <circle class="bg" cx="100" cy="100" r="85"/>
      <circle class="fill" id="arc" cx="100" cy="100" r="85"
        stroke-dasharray="534" stroke-dashoffset="534"/>
    </svg>
    <div class="val"><span id="percent">--</span><span class="unit">%</span></div>
  </div>
  <div id="warnBox"></div>
  <div class="status off" id="status">等待数据...</div>
  <div class="row">
    <div class="col"><div class="lb">📊 原始值</div><div class="vl" id="raw">--</div></div>
    <div class="col"><div class="lb">⚡ 数字输出</div><div class="vl" id="do">--</div></div>
    <div class="col"><div class="lb">📶 抖动</div><div class="vl" id="jitter">--</div></div>
  </div>
  <div class="time" id="time">--</div>
</div>

<script>
const ARC = 534;
const arc = document.getElementById('arc');
function getColor(p){
  if(p<20) return '#ff7043';
  if(p<40) return '#ffa726';
  if(p<60) return '#66bb6a';
  if(p<80) return '#29b6f6';
  return '#42a5f5';
}
async function update(){
  try{
    let r=await fetch('/data');
    let d=await r.json();
    let con = d.connected;
    document.getElementById('raw').textContent = d.raw;
    document.getElementById('do').textContent = d.dry?'🔴 高(干)':'🟢 低(湿)';
    document.getElementById('jitter').textContent = d.jitter;
    document.getElementById('time').textContent = d.time;

    let warnBox = document.getElementById('warnBox');
    let statusEl = document.getElementById('status');
    let percentEl = document.getElementById('percent');

    if(!con){
      warnBox.innerHTML = '<div class="warn">⚠️ 传感器未连接或已脱落</div>';
      statusEl.textContent = '未连接';
      statusEl.className = 'status off';
      percentEl.textContent = '--';
      arc.setAttribute('stroke-dashoffset', ARC);
      arc.setAttribute('stroke', '#37474f');
    } else {
      warnBox.innerHTML = '';
      percentEl.textContent = d.percent;
      let offset = ARC - (d.percent/100)*ARC;
      arc.setAttribute('stroke-dashoffset', offset);
      arc.setAttribute('stroke', getColor(d.percent));
      statusEl.textContent = d.dry?'干燥':'潮湿';
      statusEl.className = 'status '+(d.dry?'dry':'wet');
    }
  }catch(e){}
}
setInterval(update, 500);
update();
</script>
</body>
</html>"""

class Handler(http.server.SimpleHTTPRequestHandler):
    def do_GET(self):
        if self.path == '/data':
            self.send_response(200)
            self.send_header('Content-Type', 'application/json')
            self.send_header('Access-Control-Allow-Origin', '*')
            self.end_headers()
            self.wfile.write(json.dumps(latest).encode())
        elif self.path in ('/', '/index.html'):
            self.send_response(200)
            self.send_header('Content-Type', 'text/html; charset=utf-8')
            self.end_headers()
            self.wfile.write(HTML.encode())
        else:
            super().do_GET()

if __name__ == '__main__':
    t = threading.Thread(target=read_serial, daemon=True)
    t.start()
    print(f"🌐 http://localhost:{WEB_PORT}")
    http.server.HTTPServer(('', WEB_PORT), Handler).serve_forever()

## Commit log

2026-08-10 更新README.md
2026-08-10 更新README文件, 修改了语法错误。
2026-08-10 更新了README文件“
2026-08-11 更新README文件, 增加了中英翻译版本
2026-08-12 新增pro_intro.md,slogan.md
2026-08-13 添加土壤湿度传感器代码及硬件测试程序
    - soil-monitor: Arduino 程序 + Web 监控 + 日志脚本
    - blink-alternate: 板载 LED 测试
    - 添加 .gitignore
2026-08-13 新增Tinkercad导出的3D打印模型STL (Terrific Trug)
    [Terrific Trug (1).stl]
2026-08-13 修改了hardware文件夹,改为austin
2026-08-13 修正了文件名
    [Terrific Trug.stl]
2026-08-13 新增项目Introduction文档 (pro intro.docx)
2026-08-13 修改名称,修改文件名
2026-08-13 将 pro intro.docx 转为 md（删除重复的 docx）
2026-08-13 修改文件位置, 将pro_intro.md, slogan.md, Terrific Trug.stl移入GJJ文件夹。
    [Terrific Trug.stl]
2026-08-13 将风速传感器代码移入wanglihui文件夹
2026-08-13 将 WindSensor 代码放入 wanglihui 文件夹
2026-08-13 风速报警功能：风速>10km/h时报警，并添加README说明
2026-08-13 上传了土湿度传感器的测试照片和测试视频
2026-08-13 新增风速+温湿度监测预警系统：Arduino程序+仪表盘服务器+readme1
2026-08-13 readme1嵌入项目参考图片
2026-08-13 新增LouisGJJ模型 (Terrific Trug 分层版)
    [LouisGJJ.stl]
2026-08-13 上传全部STL模型及测量基准到GJJ文件夹
    [LouisGJJ.stl, Sizzling Jaban (1).stl, Sizzling Jaban (2).stl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]
2026-08-13 大风规则阈值改为阵风≥5m/s
2026-08-13 同步最新仪表盘：加分规则明细展示+大风≥5m/s，readme1嵌入新图片
2026-08-13 readme1图片改用相对路径引用，补齐图片1/2文件
2026-08-13 更新仪表盘架构：8001转发服务(wind_server.py)独占串口，仪表盘改为轮询8001接口；新增温湿度转发；启动脚本同时启动两个服务
2026-08-13 添加了demo1文件夹, 包含第一个demo的所有测试数据, 实现方式, 各传感器的连接方式, 少量迭代优化了预警系统,
2026-08-13 上次一样上传失败，这次重新上传。添加 demo1 文件夹：代码、说明文档、图片与屏幕录制视频，视频暂未上传（原因：文件过大）
2026-08-13 新增8/13工程笔记GJJ (山谷阵雨方案总结+今日日志)
2026-08-13 demo1: 重组为 beta1-4 版本化结构
    - zh-CN/ 与 en-US/ 各按 beta1~beta4 归档代码 + 文档（FlowSensor.ino + server.py + 说明文档.docx）
    - beta1: 原始算法 D<0.30 无门槛，水泵 D7 数字开关
    - beta2: 门槛(土壤<60%判安全) + 三级阈值 0.45
    - beta3: 水泵 D9 PWM 调速 + 网页滑块 + 功率显示
    - beta4: 尖峰检测滑动基准(自适应P95) + 整机功率
    - README 加版本历史 changelog + 更新目录树
    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
2026-08-13 新增初版山洪数学模型方案
2026-08-13 补上了demo1未上传的视频
2026-08-13 将docx文档改为易读的md文档, 同时保留docx文档。README新增版本规划段落
2026-08-14 demo1文件夹新增风速，温湿度等相关实现代码
2026-08-14 新增了算法迭代, 并更新了数学模型第一版技术文档
2026-08-14 新增数学预警模型第二版技术文档（v2：参数标定+等级0-3体系）
2026-08-14 算法迭代README补充v2文档索引
2026-08-14 update demo1 README version plan: algorithm iteration phase, ultrasonic/Manning plan dropped
2026-08-14 demo1 README改版：目录式导航（徽章+TOC+架构+场景+文档索引）
2026-08-14 更新Beta5硬件, 优化算法，并将温湿度迁移，其他详见技术文档
2026-08-14 修改了demo1里面的文件结构，以便于使用
2026-08-14 更新了Demo1的README文件，修复已知问题
2026-08-14 重写了新的README文件，保留了旧的并另设置README_CLASSIC.md文件
2026-08-14 重写外层README：CV_test风格（徽章+TOC+功能+硬件+预警模型+FAQ），旧版存README_CLASSIC，山洪数据修正为官方70%
2026-08-15 README新增仓库结构与硬件模块说明; 风速+温湿度server移除已迁移的温湿度上报

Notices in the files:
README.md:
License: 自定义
